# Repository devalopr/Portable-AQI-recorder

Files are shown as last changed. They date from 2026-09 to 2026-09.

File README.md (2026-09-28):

# Portable AQI Recorder — V3 (custom PCB)

A handheld air-quality recorder on a custom main board: an ESP32-C3-MINI-1 module reads a Sensirion SEN5x or SEN6x particulate sensor and an optional SCD4x CO₂ sensor (SCD40, SCD41 or SCD43), shows readings on a 2.4" ST7789 TFT with three buttons, and has Wi-Fi and BLE on the module.

This branch holds the **V3 main PCB only**. Everything else lives elsewhere:

| What | Where |
|---|---|
| ESP32-C3 Super Mini build without a PCB: firmware, Web Bluetooth app, wiring | [V2 branch](https://github.com/devalopr/Portable-AQI-recorder/tree/V2) |
| 18650 battery board (IP5310, USB-C in/out, battery % over PWM) | Separate product: [18650-USB-C-UPS](https://github.com/devalopr/18650-USB-C-UPS) (private) |
| Rev A boards and earlier design history | Git history of this branch (commit `34dd5cf`) |

## Main board (Rev B)

**[hardware/rev-b/main](hardware/rev-b/main/README.md)** — KiCad 10 project, 47 × 76 mm, two layers, fully routed. Start with its README: layout, pin map, connectors, cost, checks and open items before fabrication.

- **Display:** 2.4" 240 × 320 ST7789 TFT on the front, with the three buttons below it. An e-paper display can be fitted instead through an external adapter on J6.
- **Sensors:** SEN5x and SEN6x connectors (fit one PM module) and a CO₂ island for an optional SCD40, SCD41 or SCD43, soldered by hand later. Everything else on the board comes assembled; only the CO₂ sensor and the J6/J8 headers are left unfitted.
- **Power and data:** USB-C J1 is the only input. It takes 5 V and USB data from the battery board's USB-C output, or straight from a charger or computer. Battery % arrives as PWM on J2.
- **Cost:** about $4.63 per board at 1000 (parts, 2-layer fabrication and JLC assembly); see [review/COST.md](hardware/rev-b/main/review/COST.md).

## Repository layout

| Path | Contents |
|---|---|
| [firmware](firmware/README.md) | Main board firmware (PlatformIO). |
| [hardware/rev-b/main](hardware/rev-b/main/README.md) | Schematic, PCB, libraries and 3D models; `review/` has the BOM, placement file, PDF, renders, DRC/ERC reports and routing files. |
| [hardware/rev-b/scripts](hardware/rev-b/scripts) | Python/shell pipeline that generates the schematic and places, routes and checks the board (see "Regenerating" in the main README). |
| [hardware/rev-b/firmware/telemetry](hardware/rev-b/firmware/telemetry/README.md) | ESP32 receiver for the battery board's battery-% PWM signal. |
| [hardware/rev-b/references](hardware/rev-b/references) | Datasheets for parts on this board. |
| [hardware/design-brief.md](hardware/design-brief.md) | The original product brief the boards were designed from. |

## Firmware

**[firmware/](firmware/README.md)** — PlatformIO/Arduino firmware for this board, ported from the V2 firmware: auto-detects SEN5x or SEN6x and any SCD4x, shows AQI and the other readings on the TFT, records to RAM, streams over BLE (compatible with the V2 web app) and shows the battery % from the battery board. It builds but hasn't run on a built board yet.

The board is programmed and logs over its USB-C port (the ESP32-C3's native USB): switch the board on and run `pio run -t upload` in `firmware/`. If it stops appearing, hold OK while switching it on to force the bootloader.

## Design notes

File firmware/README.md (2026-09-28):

# Main board firmware (V3)

PlatformIO / Arduino firmware for the main board Rev B ([hardware/rev-b/main](../hardware/rev-b/main/README.md)). It is a port of the V2 Super Mini firmware to this board's pins, sensors and three buttons. It builds, but **it has not run on a built board yet**; see "Not yet verified" below.

## Build and flash

Needs [PlatformIO](https://platformio.org/) (the VS Code extension or `pip install platformio`). From this folder:

```bash
pio run -t upload
```

```bash
pio device monitor
```

## Programming over USB

Yes: the board is programmed and logs through its USB-C port J1, with no adapter or extra buttons.

- J1's data pair goes to the ESP32-C3's built-in USB Serial/JTAG port (GPIO18/19) through R7/R8 and the D1 ESD protector. A computer sees a USB serial port; esptool (used by `pio run -t upload`) resets the chip into the bootloader and back over USB by itself.
- **The power switch must be on.** SW4 switches the regulators that power the ESP32, so with the switch off the board is invisible to the computer even though USB is plugged in.
- It also works through the battery board: plug the computer into the battery board's input, and the battery board passes USB data to its output, which feeds J1. That pass-through is Full Speed only and untested, so use a direct cable to J1 if it misbehaves.
- **If the port disappears** (e.g. firmware that crashes at boot or reuses GPIO18/19): hold **OK** while switching the power on. GPIO9 low at power-up starts the ROM bootloader, which always comes up on USB. Flash, then switch off and on. TP3 (GPIO9) and TP2 (EN, reset) are also on the back for a test fixture.
- Serial logs use native USB CDC (`ARDUINO_USB_CDC_ON_BOOT`). Don't enable UART0: its TX pin, GPIO21, is the battery-% input.

## What it does

| Feature | Details |
|---|---|
| PM sensor | Auto-detected at boot: SEN50/54/55 on J3 (I²C 0x69) or SEN63C/65/66/68 on J4 (I²C 0x6B). Fit one. |
| CO₂ | Any SCD4x on the CO₂ island (I²C 0x62): SCD40, SCD41 or SCD43, identified at boot and logged. Otherwise the SEN63C/SEN66's built-in CO₂. The SCD4x wins if both are present. |
| AQI | US EPA AQI from PM2.5 and PM10, unchanged from V2 (above 500 continues the 301–500 slope). |
| Display | ST7789 240 × 320 on J5; home screen, full-screen charts. Backlight PWM on GPIO3 (Q1). |
| Battery | Battery % from the battery board's PWM on J2 → GPIO21 (`hardware/rev-b/firmware/telemetry`); shows `--` without it. |
| Recording | RAM ring buffer, 2700 samples (45 min at 1 Hz), charted on the device. |
| BLE | Same service and packet as V2, so the [V2 web app](https://github.com/devalopr/Portable-AQI-recorder/tree/V2/web) works. Two fields are appended (CO₂ ppm u16, battery % u8); the V2 app ignores them and shows SEN6x sensors as "Unknown". |

### Buttons

| Button | Home screen | Chart |
|---|---|---|
| LEFT / RIGHT | Move the selection | Previous / next chart |
| OK | Open the chart for the selection; on the gear, cycle brightness (100/70/40/15 %, remembered) | Back to home |
| Hold OK (0.8 s) | Start / stop recording | Start / stop recording |

Don't hold LEFT or RIGHT while switching on (they are boot-strap pins).

## Configuration

`platformio.ini` holds the display pins and `DISPLAY_ROTATION` (2 = image turned 180° because the display flex exits at the top). If the image comes out upside down on the real panel, change it to 0.

## Not yet verified on hardware

- Display orientation, colour order and inversion (`DISPLAY_ROTATION`, `TFT_RGB_ORDER`, `TFT_INVERSION_OFF`).
- Backlight brightness steps against R28.
- SEN6x start-up timing and each SEN6x variant's detection (only the drivers' interfaces were checked).
- The SCD4x on the island, and its temperature offset with the board running.
- Battery % from a real battery board.
- The e-paper option (J6) has no driver in this firmware; it builds for the TFT only.

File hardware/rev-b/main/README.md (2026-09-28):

# AQI main board — Rev B

Open `AQI_Main.kicad_pro` in KiCad 10. This board mates with the IP5310 battery board, which now lives in its own private repo, [18650-USB-C-UPS](https://github.com/devalopr/18650-USB-C-UPS). It started from the routed Rev A main board, whose design is kept in `review/rev-a-baseline/` as the input to `main_revb_design.py`; the rest of Rev A is in git history.

**47 × 76 mm, two layers, 1.6 mm.** This is 4 mm shorter and 3 mm wider than Rev A, and two layers instead of four. The previous 4-layer, 80 mm version is kept in `review/rev-b-4layer-80mm/` (board, `design.json` and its cost).

Changes in the 2-layer, 47 × 76 mm re-layout:

- **Wider, with mounting lips.** The board grew 1.5 mm on each long side, from 44 to 47 mm, for routing room. Board coordinates keep the Rev A origin, so the board now spans x = −1.5 to 45.5 mm. The outer 1 mm on each side (x = −1.5 to −0.5 and 44.5 to 45.5 mm) is a lip for clamping the board in the case. It carries only the ground pour: no tracks or vias. SW4 moved out 1.5 mm with the edge.

- **Shorter bottom.** Everything below the buttons moved up 4 mm and the bottom edge was cut to match:
  - the ESP32 module, which keeps its antenna at the edge, and its supply caps;
  - USB-C and D1;
  - the J2/J8 headers.

  The limit is USB-C: its shield legs pass through the board and must stay clear of the OK button's pads.
- **CO₂ on top.** The CO₂ island is now at the top of the right column (y = 21–35 mm, under J5), above SEN5x and SEN6x. It is fed through its bottom-right tab instead of the middle tab (see Layout). Set `ISLAND_DY = 0` in `main_revb_2layer.py` to go back to the island at the bottom of the column.
- **Sensor connectors.** J3 (SEN5x, y = 37–49 mm) and J4 (SEN6x, y = 49.8–59.4 mm) sit below the island, 6 mm in from the original right edge. Their mouths face the edge from x = 37.5 mm, leaving 8 mm on the board for the GH plug and for the cable to bend down before it reaches the case.
- **E-paper through an adapter.** The on-board e-paper boost circuit and its 24-pin FPC connector are gone. An unfitted 8-pin header J6 takes their place (see below).
- **Two layers.** The front copper, where only the buttons sit, carries ground plus as few signals as possible. A few critical nets are laid first as fixed routes (see Layout), and the rest are routed around them.

## Front: display and buttons

The front carries only the display and the three buttons. Everything else, including USB-C, is on the back.

- **Display.** A 2.4-inch 240 × 320 ST7789 panel with a 10-way, 1.0 mm-pitch flex.
  - **Size:** 42.72 × 60.26 × 2.5 mm, with a 36.72 × 48.96 mm active area (common datasheet values; you measured about 42.5 × 60 × 2.5 mm).
  - **Position:** centred in the Rev A display envelope, which spans x = 0.64–43.36 mm, y = 1.5–62.46 mm (board origin top-left, seen from the front). The panel itself spans y = 1.85–62.11 mm.
  - **Height:** it sits on 0.2 mm tape, so its front face is 2.7 mm above the board.
  - **Flex:** exits at the top, wraps over the top edge (about 1.5 mm past it) and runs into J5 on the back. The active area therefore sits toward the buttons, and firmware rotates the image.
  - **In the files:** the board-only footprint DS1 carries the panel's 3D model and outline. It isn't in the BOM or the placement file. The envelope is also drawn on Dwgs.User, labelled "TFT DISPLAY BODY (FRONT)".
  - The active-area offsets (3.0 mm at the sides, 3.2 mm at the far end, 8.1 mm at the flex end) and the flex path are typical values, not from your panel's drawing. Check them against the part you buy.
  - Nothing is placed on the front under the panel.
- **Buttons.** SW1 LEFT, SW2 OK and SW3 RIGHT sit in one row directly below the display:
  - centres at x = 9, 22 and 35 mm, y = 66.25 mm;
  - an even 13 mm pitch, centred on the board and the display (x = 22);
  - XKB TS-1187A: 5.1 × 5.1 mm body, 1.5 mm tall;
  - bodies at y = 63.7–68.8 mm, about 1.2 mm below the display edge.

  The switch tops (1.5 mm) are 1.2 mm below the display face (2.7 mm), so the enclosure needs button caps or plungers that reach the front face. The silkscreen labels L / OK / R are under each button.
- **3D models.** They are all in `lib/3d/` and the footprints point at them through `${KIPRJMOD}`; see `lib/3d/README.md`.
  - USB-C uses the LCSC catalogue model shared with the battery board.
  - KiCad 10 has no models for the TS-1187A buttons or the MSK12C02 power switch. They use simplified envelopes built from the footprint and datasheet dimensions, with their build123d sources alongside.

## Cost

About **$4.63 (₹444) per board at 1000** boards:

| At 1000 boards | Per board |
|---|---:|
| Parts | $4.01 |
| 2-layer fabrication, 47 × 76 mm | $0.13 (4-layer, 80 mm was $0.30) |
| JLC assembly | $0.49 |

Five prototypes cost about $31 each, mostly JLC's per-order assembly setup; the bare 2-layer boards are about $2 for five. Details, assumptions and exclusions are in [review/COST.md](review/COST.md). Only the SCD41 (U8) and the J6/J8 headers are unfitted; the CO₂ supply (LDO U7 with C15, C16 and C42, about $0.24) is assembled so the sensor can be soldered in later on its own. The same design with its original parts was about $10.7 (₹1030) at 1000.

## E-paper option (J6, unfitted)

The stationary version can use an e-paper display instead of the TFT. The panel from the Rev A brief, Good Display GDEY037T03, is a bare panel: it needs a boost circuit (about ±15 V gate and source rails) on whatever board its 24-pin flex plugs into. Rev A put that circuit on this board as an unfitted option: 22 parts plus the FPC connector. Rev B leaves the boost circuit to an external adapter instead:

- **Adapter.** Good Display's DESPI-C02 takes the panel's 24-pin flex and makes the rails. The same adapter fits most of Good Display's 24-pin SPI panels, so the main board isn't tied to one panel. A module with its own driver board (for example Waveshare's) also works.
- **J6.** A 1 × 8, 2.54 mm SMD pin header on the back at the top-left edge (pads staggered at x = 3.35 and 6.66 mm, y = 1.5–19.3 mm). Like J8, it is unfitted (DNP) by default and is left out of the JLC BOM and placement files; solder it by hand for an e-paper build. It sits near the board edge, clear of J5, so there's room for the iron. It's surface-mount so no through-hole pads sit under the TFT in the default build. Pin 1 is at the top; the pin names are on the back silkscreen, on the side toward J5.

| J6 pin | DESPI-C02 pin | Signal | ESP32 |
|---:|---|---|---|
| 1 | BUSY | EPD_BUSY | GPIO20 |
| 2 | RES | DISP_RST | GPIO7 |
| 3 | D/C | DISP_DC | GPIO10 |
| 4 | CS | DISP_CS | GPIO4 |
| 5 | SCK | DISP_SCK | GPIO5 |
| 6 | SDI | DISP_MOSI | GPIO6 |
| 7 | GND | GND | |
| 8 | 3.3V | +3V2 (3.19 V) | |

A straight 8-way female-to-female cable maps J6 pin n to DESPI-C02 pin n. Waveshare modules use the same signals in reverse order (VCC, GND, DIN, CLK, CS, DC, RST, BUSY).

The display SPI, CS, DC and reset are shared with the TFT, so **fit one display only**. The adapter's supply comes from the +3V2 rail; e-paper refresh current is small. Firmware still has to supply a driver for the chosen panel: ESPHome has no working UC8253 (GDEY037T03) driver yet (see the Rev A brief), so either pick a panel ESPHome supports or bench-test a custom component.

## Interface to the battery board

- **USB-C J1 is the only power and data input.** It is the same SHOU HAN TYPE-C 16P L6.5 (LCSC C49287211) as the battery board's J1 and J7, using that board's footprint (checked against the maker's drawing) and 3D model. It is on the back, at x = 26.7 mm on the bottom edge (y = 76), with its mouth flush with the edge. That is about 11 mm nearer the centre than in Rev A. Plug it into the battery board's USB-C output J7, which carries 5 V plus USB data passed through from the battery board's input port. It can also plug straight into a computer or adapter.
- **J2: straight 2.54 mm Dupont header for battery %** (hanxia HX PZ2.54-1x2P ZZ, LCSC C32713268), back side, bottom-right, pin 1 at (33.85, 72.1) mm. The pins stand up from the back, toward the battery board; nothing overhangs the edge. Pin 1 = GND, pin 2 = BAT_PWM, the same order as battery J9, so a straight female-female jumper works. R33 (10 kΩ) pulls BAT_PWM up to +3V2; R34 (1 kΩ) feeds GPIO21. Encoding and receiver: `../firmware/telemetry/README.md`.
- **J8: straight Dupont header for external 5 V, unpopulated** (same part), next to J2 (pin 1 at x = 39.95 mm). Pin 1 = GND, pin 2 = 5 V in. D2 (B5819W Schottky, fitted) feeds +5V_SYS, the same point as USB VBUS. The switch and regulators work as normal, and the diode stops the board back-feeding the external supply. A supply above USB VBUS + 0.3 V can back-feed a connected USB host, so don't plug USB into a computer while an external 5 V is attached.
- Removed with the 10-way JST GH link:
  - the TS3USB30E USB data mux;
  - the TPS2116 power mux;
  - their FETs and resistors;
  - C4, C5, C6 and R24.

  No I2C runs to the battery board any more.

## Cost-down changes (same functions)

| Part | Rev A | Rev B |
|---|---|---|
| U5, U6 bucks | TPS62160 (MSOP-8) | Silergy SY8089A1AAC (SOT-23-5). The datasheet's optional feed-forward caps are omitted. |
| Buttons | MCP23008 I2C expander + C&K KMR2 | Straight to GPIOs; XKB TS-1187A 5.1 mm switches. U9, C17, R23 and R25 removed. |
| Backlight | STCS05A current sink (not stocked at JLC) | AO3400A low-side switch Q1 with R28 = 33 Ω 1206 (~55 mA at Vf 3.1 V). Still PWM-dimmable on GPIO3; the current is set by the resistor, not regulated. |
| Power switch | C&K JS102011SAQN | Shou Han MSK12C02; its actuator sticks out about 1.1 mm past the right edge. |
| USB-C | GCT USB4105 | SHOU HAN TYPE-C 16P L6.5, the battery board's part ($0.047 at 1000, against $0.103 for the HRO TYPE-C-31-M-12 it replaced) |
| Sensor connectors J3, J4 | JST GH | XYECO GH-compatible clones, same footprint |
| ESD, MCU | ST USBLC6-2SC6, ESP32-C3-MINI-1-H4 | Tech Public USBLC6-2SC6, ESP32-C3-MINI-1-H4X (same footprint) |

Every fitted part has an LCSC code in the schematic. `review/jlc-bom.csv` and `review/jlc-cpl.csv` are ready for JLCPCB assembly. The board is double-sided: the three buttons are on the front and everything else is on the back.

The TFT connector (TE 1-84953-0, $0.44) stays: no cheap top-contact 1.0 mm 10-pin FPC connector is stocked, and the display needs top contact.

## Firmware pin map

The firmware in [firmware/](../../../firmware/README.md) uses this map. The board is programmed and logs over J1 (native USB); see that README.

| ESP32 GPIO | Function |
|---|---|
| 10 | Display DC |
| 4 | Display CS |
| 5 | Display SCK |
| 6 | Display MOSI |
| 7 | Display RST |
| 8 | LEFT button, active low, R3 pull-up |
| 9 | OK button, active low, R2 pull-up. Hold OK while resetting to enter the ROM bootloader. |
| 2 | RIGHT button, active low, R4 pull-up |
| 21 | BAT_PWM input through R34. Use native USB for logs; do not enable UART TX on GPIO21. |
| 3 | Backlight PWM, now driving a MOSFET gate (R27 pull-down) |
| 0 | I²C SDA (SEN5x at 0x69, SEN6x at 0x6B, SCD4x at 0x62) |
| 1 | I²C SCL |
| 20 | E-paper BUSY (J6 pin 1), input; also the ROM UART RX |
| 18, 19 | Native USB D−, D+ (to J1 through R7/R8 and D1) |

GPIO2, 8 and 9 are boot-strap pins. Don't hold LEFT or RIGHT while resetting; OK held at reset is the intended download mode. The buttons need a pull-up at reset, which R2–R4 provide; there's no I2C expander any more.

The 2-layer layout changed the display pins so they leave the module in the TFT connector's order (DC, CS, SCK, MOSI, RST); this lets the bus run without crossings:

| | Rev A and 4-layer Rev B | 2-layer Rev B |
|---|---|---|
| DC | GPIO5 | GPIO10 |
| CS | GPIO10 | GPIO4 |
| SCK | GPIO4 | GPIO5 |

MOSI (GPIO6) and RST (GPIO7) are unchanged. The display SPI goes through the GPIO matrix either way. The table above is the complete pin map.

## Layout

Two layers. Nearly every part is on the back, so the back carries most signals, and the front carries ground plus the fixed routes below.

- **Ground.**
  - Both layers are poured with GND and stitched with 228 vias:
    - one beside every ground pad, placed before routing so the router must leave room for it;
    - a 2 mm edge fence;
    - a 3 mm field grid;
    - repair vias for any pocket.
  - All ground copper is one connected area except the CO₂ island, which joins through the bridge (see below).
  - The front pour covers about 76% of the board and the back about 64%.
- **Ground neck.** The CO₂ island's slots cut the right half of the board between y = 21 and 35 mm, so every return current between the top and bottom halves passes through the neck on the left. The front copper at x = 8.5–16 mm, y = 23.3–35.5 mm is kept free of signal tracks; vias are allowed. That keeps a continuous 7.5 mm ground bridge there.
- **Fixed routes** (drawn before autorouting, in `main_revb_2layer.py`):
  - **Display SPI.** DC, CS, SCK, MOSI and RST run as a 5-lane front bus. It starts with vias above the module's top pins, runs up the left edge and along y = 21–23 mm, then drops through vias beside J5's pads.
  - **Backlight PWM.** It takes the outermost left-edge lane.
  - **CO₂ island.** The island's copper enters through its 2.5 mm bottom-right tab (x = 41.5–44 mm, y = 34–35 mm); the left tab is mechanical only, with no copper. U8 (SCD41) is turned so its SDA, SCL, VDD and GND pins face the tab. SDA and GND cross on the back, SCL and +3V3_CO2 on the front, and they run down to U7 (the CO₂ LDO, beside J3) and the I²C bus. The widened strip beside the island (x = 44–45.5 mm) has no copper at all, so the island stays thermally isolated. Tracks keep 0.35 mm from all slot edges. The U8 footprint takes any SCD4x: the BOM lists the SCD41, but an SCD40 (cheaper, specified to 2000 ppm) or SCD43 (better accuracy) fits and works with the firmware unchanged.
  - **Buttons.**
    - GPIO8 (LEFT) runs straight down the front.
    - GPIO9 (OK) goes past the module corner on the back, then down the front.
    - GPIO2 (RIGHT) leaves pin 5 on the back, up a via in the lane beside the module's centre ground pads, then along the front between the button pad rows.
  - **Battery PWM (GPIO21).** It crosses the bottom band on the front at y = 65.45 mm.
  - **E-paper BUSY.** It runs up the front from the module to TP5; the router takes it on to J6.
  - **USB.** The module-side pair threads past the pin-30/31 vias. D1's ground goes through a via under its body to the USB-C shield.
  - **Load switch U4.** CT, ON and QOD go directly to C8, R15 and R16.
- **Placement changes for two layers.**
  - U4 (load switch) took the CO₂ LDO U7's place and is turned 180°, so its control pins face their parts. U7 moved beside J3's 5 V pin, just below the island.
  - R7/R8 swapped, so the USB pair keeps the same order from the module through the resistors to D1.
  - R27, the backlight gate pull-down, sits beside Q1 between its gate and source pins (it was at the end of the left-edge backlight lane, where J6 now is).
  - C16 (the SCD41's 10 µF supply cap, assembled) is off the island, below U7's output (x = 25 mm, y = 42 mm), about 7 mm from the sensor body and across the slot. Hot air used to fit the SCD41 later won't lift it. It also acts as U7's bulk output cap. The island itself now carries only the sensor.
  - TP2/TP3 moved to the left edge (the touch-up moves TP3 beside R3 only if the router can't reach it there); C7, R2 and R3 moved up 1.5–3 mm to open a fan-out band above the module's top pins.
- **Routing and power.**
  - Freerouting routes the rest, with the back preferred. An A* finisher (`astar_finish.py`) closes what the router leaves, moving other tracks only when everything it moves reconnects.
  - Power nets are 0.6 mm except a few short 0.4–0.5 mm squeezes (about 6.5 mm of +3V2, 5 mm of +5V_SYS and 3 mm of +5V_SW). +3V3_CO2 is 0.25 mm through the island tab; the SCD41's peak draw is under 0.2 A.
- **Bucks.** Each SY8089's input cap, IC and inductor sit together on the back. Their grounds join the back pour, with vias to the front plane beside each ground pad.

## Checks (review/)

- **Results:** ERC 0. DRC with schematic parity: 0 errors, 0 warnings, 0 unconnected, 0 parity issues.
- **Exports:** `AQI_Main.pdf`, `netlist.xml`, `engineering-bom.csv`, `jlc-bom.csv`, `jlc-cpl.csv`, `COST.md`, `price-snapshot-2026-09-27.json`, `drc.json`, `erc.json`, layer SVGs and renders.
- **3D renders:** `main-top.png`, `main-bottom.png` and the two angled views. They include the display panel and its flex.
- `rev-a-baseline/` holds the untouched Rev A board and its `design.json` (the input to `main_revb_design.py`); `rev-b-4layer-80mm/` holds the 4-layer, 80 mm Rev B that the 2-layer layout starts from.
- `routing/` holds the Freerouting input and output (`AQI_Main.dsn`, `.ses`, logs) and the list of fixed routes.

## Regenerating

Needs KiCad 10, a Java 25+ runtime (Homebrew `openjdk`) and Freerouting 2.4.1 (`~/Applications/freerouting/freerouting-2.4.1.jar`, or set `FREEROUTING`). Run from `../scripts`:

1. `main_revb_design.py` rebuilds `design.json` and the schematic.
2. Export `review/netlist.xml` (kicad-cli `sch export netlist --format kicadxml`).
3. `main_revb_2layer.sh` starts from `review/rev-b-4layer-80mm/` and runs each stage in turn:
   1. **Placement:** strips the copper, cuts the outline, moves parts, lays the fixed routes and ground fan-out, and writes the DSN.
   2. **Routing:** Freerouting, then the A* finisher.
   3. **Ground:** stitching and island repair.
   4. **Touch-up:** `main_revb_2layer_touchup.py`.
   5. **Sync:** writes positions back to `design.json`.
   6. **DRC.**
4. `main_revb_cost.py` recomputes `review/COST.md`. It picks up the layer count and board size from the board.

Freerouting's result depends on its input, so a rerun after any change gives a different board, and the finisher may need a hand. The 4-layer flow (`main_revb_layout.py`) still rebuilds the 80 mm board.

Hand edits made in KiCad are not captured by the scripts. Once you edit the `.kicad_pcb` by hand, treat it as the source of truth.

## Open items before fabrication

1. **Antenna.** The module sits on the back, facing the battery board. Keep the 18650 cell, holder terminals and cables away from the bottom-left corner.
   - With the shorter board, the antenna keepout ends about 1.3 mm from the LEFT button's pads (it was 5 mm).
   - USB-C is about 6 mm from the keepout.
   - Measure Wi-Fi/BLE range in the enclosure, with the USB cable plugged in.
   - On two layers the module also has no inner ground plane under it; its ground pads stitch to the front pour instead.
2. **Backlight current.** R28 = 33 Ω assumes a ~3.1 V LED forward voltage at ~55 mA. Check brightness and current on the actual panel and adjust R28.
3. **Enclosure.** Allow for:
   - the 47 × 76 mm board, with the 1 mm copper-free clamping lips on both long sides;
   - the J2/J8 straight headers: about 8.5 mm tall on the back, plus the Dupont housings (your CAD test fit shows room);
   - J3/J4 mouths at x = 37.5 mm, with the GH plug and cable bend in the 8 mm to the right edge;
   - the SW4 actuator about 1.1 mm past the right edge;
   - USB-C on the back at x = 26.7 mm;
   - the button row at x = 9, 22, 35 mm, y = 66.25 mm, with caps or plungers to reach past the display thickness.
4. **2-layer review.** Before ordering, look over the routing in KiCad, especially:
   - the CO₂ island's tab feed;
   - the U4 corner by the slot;
   - the left-edge display bus.
5. **Firmware.** [../../../firmware](../../../firmware/README.md) implements the pin map above (buttons on GPIO8/9/2, battery % from BAT_PWM, the display on DC = GPIO10, CS = GPIO4, SCK = GPIO5). On the first board, check the display orientation and colours, backlight steps and sensor detection. The e-paper build still needs BUSY on GPIO20 and a driver for the chosen panel.
6. **USB-C supply and fit.** LCSC had only 2,553 of C49287211 in stock (2026-09-27). The battery board uses two per set, so 1000 sets need 3000. Reserve stock or approve the HRO TYPE-C-31-M-12 as the alternate, which needs a footprint and breakout change. SHOU HAN's drawing is for 0.8 mm boards, so check shell-leg soldering and retention on this 1.6 mm board. The battery board has the same open check. In JLC's placement preview, confirm J1's rotation: its footprint comes from the EasyEDA catalogue.
7. **Pricing.** Get a real JLCPCB quote. The cost uses catalogue tiers and published assembly rates, not a quotation.
8. **Carried over from Rev A:**
   - Finish the enclosure CAD: TFT flex bend radius, connector latch access, button caps and travel, PCB retention on the lips, sensor airflow. Support the CO₂ island without a conductive metal bridge.
   - Standalone sensing needs a suitable 5 V supply (start with a 1 A or larger adapter); the board does not detect Type-C advertised current.
   - Check MLCC effective capacitance under DC bias for the fitted parts.
   - Validate the CO₂ temperature offset with Wi-Fi, the display and the PM sensor running; couple the CO₂ opening to ambient air and shield it from PM fan turbulence.
   - Validate USB signal quality, regulator transients and backlight PWM on the built board.

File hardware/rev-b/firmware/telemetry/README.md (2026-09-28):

# Battery PWM interface, revision 1

Current battery schematic: `integrated-power/AQI_IP5310_Power.kicad_sch` in the [18650-USB-C-UPS](https://github.com/devalopr/18650-USB-C-UPS) repo, which also holds the CH32 transmitter firmware and a copy of this folder. The older `cost-revision` is preserved for history. Portable ADC/estimator and charging integration now lives in that repo's `firmware/control`; target hardware binding remains unfinished.
Main schematic: `../../main-pwm/AQI_Main.kicad_sch`.
These are circuit revisions; the existing routed boards do not implement this interface yet. Do not manufacture from old STEP/ZIP/Gerber files as if they did.

## Electrical connection

Current integrated-power revision: J9 pin 2 and TP8 carry open-drain BAT_PWM; J9 pin 1 is GND. The receiver supplies its 10k pull-up to 3.3V. J3/GH and its USB branch have been removed. Older main-pwm hardware still brings this signal to GH pin 7 and needs an adapter or connector revision. Older I2C battery-interface firmware is incompatible.

Q5 is a 2N7002 open-drain output, source to GND, gate driven by CH32V003 PC1/package pin11. R49 (100k) holds the gate off during reset. Connect a **10k pullup to the host's 3.3V or 5V logic supply**, and share ground. Do not pull up to battery voltage. No pullup is fitted on the battery board, avoiding back-power into an unpowered host. Intended for short internal/hobby wiring, not a long external cable or an ESD-qualified industrial port.

Main revision: R33 pulls BAT_PWM up to +3V2; R34 (1k) connects it to ESP32 GPIO21/package pin31. TP4 is now BAT_PWM_MCU. The resistor limits contention during ROM UART output at startup. Use native USB logging and configure GPIO21 as input; do not enable UART TX on it. Sensor I2C, native USB and e-paper BUSY/GPIO20 are unchanged. Main schematic ERC and all intended connected pins in the exported netlist have been checked.

## Encoding

100Hz nominal, 10ms frame. **HIGH duty** = 10% + 0.8 × percentage, so 0% battery is 1ms high, 50% is 5ms high, and 100% is 9ms high. The MOSFET inverts its gate signal; the CH32 driver accounts for that.

Decode `percent = (high_time / period - 0.1) / 0.8 * 100`. No transitions means unavailable, never 0% or 100%. Receiver accepts periods 9–11ms, tolerates 9–91% wire duty at the endpoints, requires three valid complete frames, and expires the last value after 100ms. This is an approximate voltage-based estimate, not a calibrated fuel gauge.

## Firmware

- `battery_pwm.h`: shared encoding/decoding, no framework dependency.
- The CH32V003 transmitter (`battery_pwm_ch32.c`) is battery-board firmware and lives in the [18650-USB-C-UPS](https://github.com/devalopr/18650-USB-C-UPS) repo (`firmware/telemetry`), which has the full copy of this interface.
- `BatteryPwmReader.h/.cpp`: ESP32 Arduino receiver using a GPIO edge interrupt, no busy-wait pulse reads.
- `receiver_example.cpp` and `platformio.ini`: standalone GPIO21/USB diagnostic example, successfully built for ESP32-C3 using Arduino-ESP32 2.0.14. This example is not the AQI application and should not replace it wholesale.

Build receiver: `pio run -d hardware/rev-b/firmware/telemetry` from repository root.
Run protocol test: `clang -Wall -Wextra -Werror hardware/rev-b/firmware/telemetry/test_protocol.c -o /tmp/aqi-pwm-test && /tmp/aqi-pwm-test`.

Hardware validation still required: waveform/polarity and startup on both boards, 3.3V/5V pullups, host unpowered behavior, estimator calibration, and worst-case ISR latency. No hardware test is claimed.

Sources: WCH official SDK https://github.com/openwch/ch32v003 ; ESP32-C3-MINI pinout https://documentation.espressif.com/esp32-c3-mini-1_datasheet_en.html .

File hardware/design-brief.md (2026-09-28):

# AQI recorder design brief

> **Status (V3):** this is the original product brief, written for Rev A. The current main board is [rev-b/main](rev-b/main/README.md), which supersedes the Rev A sizes and decisions below. The battery board sections now belong to the separate [18650-USB-C-UPS](https://github.com/devalopr/18650-USB-C-UPS) repo. Rev A files and the early research it mentions are in git history (commit `34dd5cf`).

The implementation and current decisions are documented in the Rev A README (git history; the current board is described in [rev-b/main](rev-b/main/README.md)). Main PCB size is 44 × 80 mm, following the user's request to stay close to 80 mm. The TFT uses a rear top-contact connector; its flex contacts face away from the board. The battery board uses a standard 65 mm cell with PCB protection and a 10-way JST GH internal link.

The final KiCad files are engineering review prototypes. See the validation report and release items in the README before fabrication. Earlier circuit proposals under references/early-research are superseded.

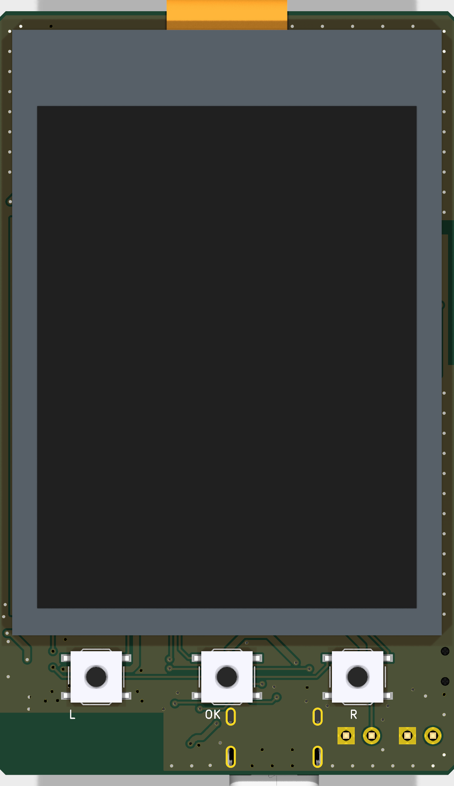
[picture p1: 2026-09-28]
hardware/rev-b/main/review/main-top.png

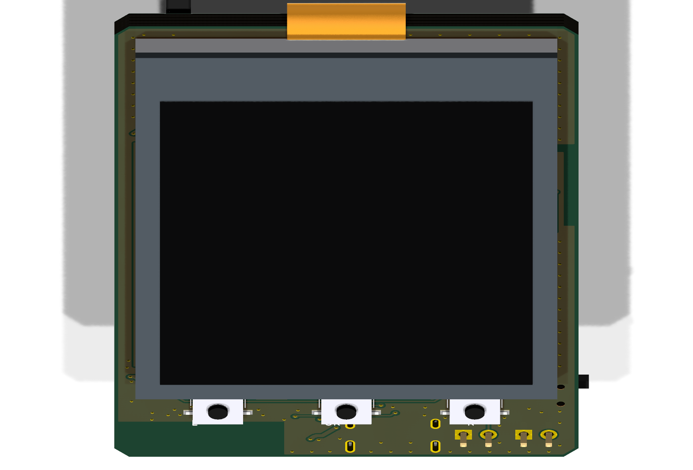
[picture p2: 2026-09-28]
hardware/rev-b/main/review/main-top-angled.png

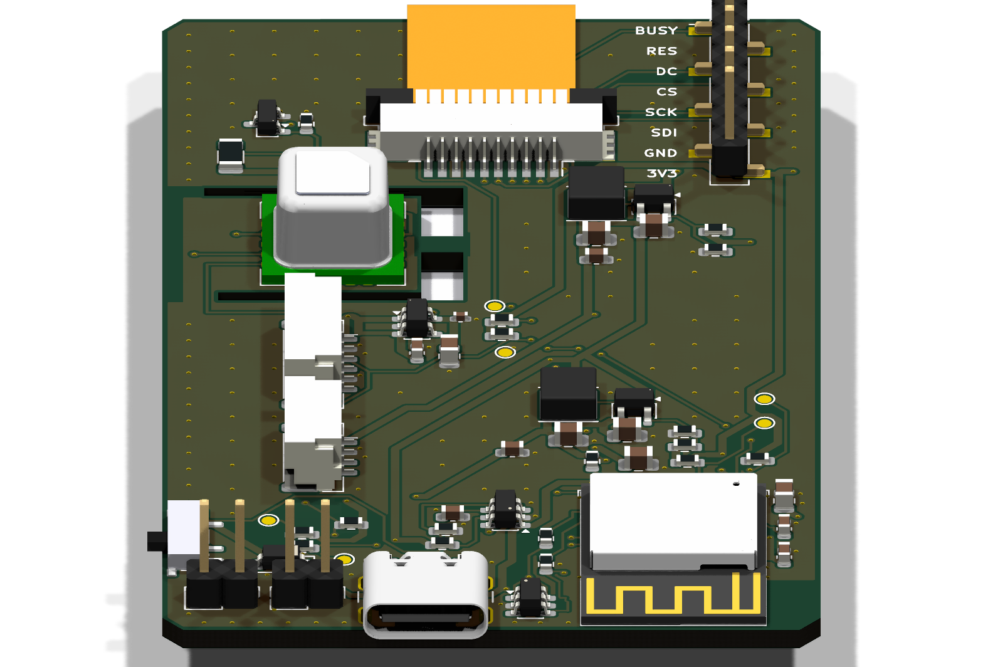
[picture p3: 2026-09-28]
hardware/rev-b/main/review/main-bottom-angled.png

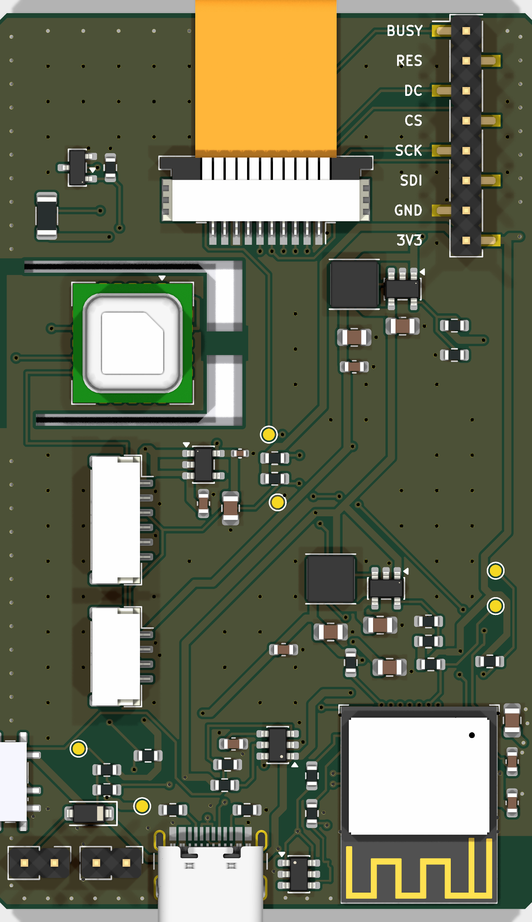
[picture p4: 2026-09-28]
hardware/rev-b/main/review/main-bottom.png

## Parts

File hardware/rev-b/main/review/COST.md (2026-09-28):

# Main board Rev B — cost estimate

Catalogue snapshot 2026-09-27 (PCBParts JLC/LCSC, `price-snapshot-2026-09-27.json`), USD, INR at 96/USD. Default TFT + SEN5x/SEN6x build; DNP parts (the SCD41 U8 and the J6/J8 headers) excluded; the CO2 supply (U7, C15, C16, C42) is fitted. JLCPCB Standard PCBA, double-sided (buttons on the front, everything else including USB-C on the back). Not a quotation.

Solder joints per board: 222 SMT, 6 through-hole. 33 unique placed parts.

| Per board | 5 prototypes | 1000 boards |
|---|---:|---:|
| Parts | $5.95 (INR 572) | $4.01 (INR 385) |
| PCB fabrication (2-layer, 47 x 76 mm) | $0.40 (INR 38) | $0.13 (INR 12) |
| Assembly (setup, stencil, feeders, joints) | $24.78 (INR 2378) | $0.49 (INR 47) |
| **Total** | $31.13 (INR 2988) | $4.63 (INR 444) |

Excludes shipping, import duty and GST, programming/test, the display, PM/CO2 sensors, enclosure and the battery board. JLC may add attrition parts; small orders also pay per-order minimums.

## Parts at 1000 boards

| Refs | Part | LCSC | Library | Qty | Unit $ | Line $ |
|---|---|---|---|---:|---:|---:|
| U1 | ESP32-C3-MINI-1-H4X | C41349510 | extended | 1 | 2.1209 | 2.121 |
| J5 | TFT TOP CONTACT | C3168738 | extended | 1 | 0.4418 | 0.442 |
| C10,C13 | 22uF 10V | C45783 | basic | 2 | 0.1116 | 0.223 |
| C2,C7,C9,C12,C16 | 10uF 25V | C15850 | basic | 5 | 0.0442 | 0.221 |
| U4 | TPS22917DBVR | C2681320 | extended | 1 | 0.1967 | 0.197 |
| U7 | TPS7A2033PDBVR | C2862740 | extended | 1 | 0.1207 | 0.121 |
| C1,C15 | 1uF 16V | C15849 | basic | 2 | 0.0543 | 0.109 |
| U5,U6 | SY8089A1AAC | C479074 | extended | 2 | 0.0520 | 0.104 |
| L1,L2 | 2.2uH SWPA4020S | C83423 | extended | 2 | 0.0442 | 0.088 |
| Q1 | AO3400A | C20917 | basic | 1 | 0.0520 | 0.052 |
| J1 | USB-C / standalone | C49287211 | extended | 1 | 0.0470 | 0.047 |
| J3 | SEN5x / 5V | C51940119 | extended | 1 | 0.0434 | 0.043 |
| SW4 | POWER / MSK12C02 | C431540 | extended | 1 | 0.0410 | 0.041 |
| J4 | SEN6x / 3.3V | C51940118 | extended | 1 | 0.0359 | 0.036 |
| D1 | USBLC6-2SC6 | C2827654 | extended | 1 | 0.0309 | 0.031 |
| C3,C11,C14 | 100nF 25V | C14663 | basic | 3 | 0.0073 | 0.022 |
| D2 | B5819W | C8598 | basic | 1 | 0.0192 | 0.019 |
| SW1 | LEFT | C318884 | basic | 1 | 0.0138 | 0.014 |
| SW2 | OK | C318884 | basic | 1 | 0.0138 | 0.014 |
| SW3 | RIGHT | C318884 | basic | 1 | 0.0138 | 0.014 |
| R15,R17,R19,R27 | 100kR | C25803 | basic | 4 | 0.0024 | 0.010 |
| J2 | BAT PWM / Dupont | C32713268 | extended | 1 | 0.0088 | 0.009 |
| C8 | 1nF 25V | C1588 | basic | 1 | 0.0068 | 0.007 |
| R1-R4,R33 | 10kR | C25804 | basic | 5 | 0.0013 | 0.006 |
| R21,R22 | 4.7kR | C23162 | basic | 2 | 0.0022 | 0.004 |
| C42 | 100nF 16V | C1525 | basic | 1 | 0.0034 | 0.003 |
| R20 | 22kR | C31850 | basic | 1 | 0.0031 | 0.003 |
| R28 | 33R | C25375 | extended | 1 | 0.0027 | 0.003 |
| R7,R8 | 22R | C23345 | basic | 2 | 0.0013 | 0.003 |
| R16 | 100R | C22775 | basic | 1 | 0.0025 | 0.003 |
| R5,R6 | 5.1kR | C23186 | basic | 2 | 0.0012 | 0.002 |
| R34 | 1kR | C21190 | basic | 1 | 0.0020 | 0.002 |
| R18 | 23.2kR | C49656146 | extended | 1 | 0.0011 | 0.001 |

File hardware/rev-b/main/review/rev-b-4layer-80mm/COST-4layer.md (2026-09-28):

# Main board Rev B — cost estimate

Catalogue snapshot 2026-09-27 (PCBParts JLC/LCSC, `price-snapshot-2026-09-27.json`), USD, INR at 96/USD. Default TFT + SEN5x/SEN6x build; DNP parts (e-paper, CO2, J8 header) excluded. JLCPCB Standard PCBA, double-sided (buttons on the front, everything else including USB-C on the back). Not a quotation.

Solder joints per board: 211 SMT, 6 through-hole. 31 unique placed parts.

| Per board | 5 prototypes | 1000 boards |
|---|---:|---:|
| Parts | $5.58 (INR 536) | $3.80 (INR 365) |
| PCB fabrication (4-layer, 44 x 80 mm) | $1.60 (INR 154) | $0.30 (INR 28) |
| Assembly (setup, stencil, feeders, joints) | $24.15 (INR 2318) | $0.47 (INR 45) |
| **Total** | $31.33 (INR 3008) | $4.57 (INR 439) |

Excludes shipping, import duty and GST, programming/test, the display, PM/CO2 sensors, enclosure and the battery board. JLC may add attrition parts; small orders also pay per-order minimums.

## Parts at 1000 boards

| Refs | Part | LCSC | Library | Qty | Unit $ | Line $ |
|---|---|---|---|---:|---:|---:|
| U1 | ESP32-C3-MINI-1-H4X | C41349510 | extended | 1 | 2.1209 | 2.121 |
| J5 | TFT TOP CONTACT | C3168738 | extended | 1 | 0.4418 | 0.442 |
| C10,C13 | 22uF 10V | C45783 | basic | 2 | 0.1116 | 0.223 |
| U4 | TPS22917DBVR | C2681320 | extended | 1 | 0.1967 | 0.197 |
| C2,C7,C9,C12 | 10uF 25V | C15850 | basic | 4 | 0.0442 | 0.177 |
| U5,U6 | SY8089A1AAC | C479074 | extended | 2 | 0.0520 | 0.104 |
| L1,L2 | 2.2uH SWPA4020S | C83423 | extended | 2 | 0.0442 | 0.088 |
| C1 | 1uF 16V | C15849 | basic | 1 | 0.0614 | 0.061 |
| Q1 | AO3400A | C20917 | basic | 1 | 0.0520 | 0.052 |
| J1 | USB-C / standalone | C49287211 | extended | 1 | 0.0470 | 0.047 |
| J3 | SEN5x / 5V | C51940119 | extended | 1 | 0.0434 | 0.043 |
| SW4 | POWER / MSK12C02 | C431540 | extended | 1 | 0.0410 | 0.041 |
| J4 | SEN6x / 3.3V | C51940118 | extended | 1 | 0.0359 | 0.036 |
| D1 | USBLC6-2SC6 | C2827654 | extended | 1 | 0.0309 | 0.031 |
| C3,C11,C14 | 100nF 25V | C14663 | basic | 3 | 0.0073 | 0.022 |
| D2 | B5819W | C8598 | basic | 1 | 0.0192 | 0.019 |
| J2 | BAT PWM / Dupont | C32713261 | extended | 1 | 0.0143 | 0.014 |
| SW1 | LEFT | C318884 | basic | 1 | 0.0138 | 0.014 |
| SW2 | OK | C318884 | basic | 1 | 0.0138 | 0.014 |
| SW3 | RIGHT | C318884 | basic | 1 | 0.0138 | 0.014 |
| R15,R17,R19,R27 | 100kR | C25803 | basic | 4 | 0.0024 | 0.010 |
| C8 | 1nF 25V | C1588 | basic | 1 | 0.0068 | 0.007 |
| R1-R4,R33 | 10kR | C25804 | basic | 5 | 0.0013 | 0.006 |
| R21,R22 | 4.7kR | C23162 | basic | 2 | 0.0022 | 0.004 |
| R20 | 22kR | C31850 | basic | 1 | 0.0031 | 0.003 |
| R28 | 33R | C25375 | extended | 1 | 0.0027 | 0.003 |
| R7,R8 | 22R | C23345 | basic | 2 | 0.0013 | 0.003 |
| R16 | 100R | C22775 | basic | 1 | 0.0025 | 0.003 |
| R5,R6 | 5.1kR | C23186 | basic | 2 | 0.0012 | 0.002 |
| R34 | 1kR | C21190 | basic | 1 | 0.0020 | 0.002 |
| R18 | 23.2kR | C49656146 | extended | 1 | 0.0011 | 0.001 |

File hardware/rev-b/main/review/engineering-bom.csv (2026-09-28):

Refs | Value | Footprint | MPN | Manufacturer | LCSC | DNP | Qty
C1,C15 | 1uF 16V | Capacitor_SMD:C_0603_1608Metric |  |  | C15849 |  | 2
C2,C7,C9,C12,C16 | 10uF 25V | Capacitor_SMD:C_0805_2012Metric |  |  | C15850 |  | 5
C3,C11,C14 | 100nF 25V | Capacitor_SMD:C_0603_1608Metric |  |  | C14663 |  | 3
C8 | 1nF 25V | Capacitor_SMD:C_0603_1608Metric |  |  | C1588 |  | 1
C10,C13 | 22uF 10V | Capacitor_SMD:C_0805_2012Metric |  |  | C45783 |  | 2
C42 | 100nF 16V | Capacitor_SMD:C_0402_1005Metric |  |  | C1525 |  | 1
D1 | USBLC6-2SC6 | Package_TO_SOT_SMD:SOT-23-6 | USBLC6-2SC6 | TECH PUBLIC | C2827654 |  | 1
D2 | B5819W | Diode_SMD:D_SOD-123 | B5819W SL | Changjiang | C8598 |  | 1
J1 | USB-C / standalone | AQI:USB-C-SMD_TYPE-C-16P-L6.5 | TYPE-C 16P L6.5 | SHOU HAN | C49287211 |  | 1
J2 | BAT PWM / Dupont | Connector_PinHeader_2.54mm:PinHeader_1x02_P2.54mm_Vertical | HX PZ2.54-1x2P ZZ | hanxia | C32713268 |  | 1
J3 | SEN5x / 5V | Connector_JST:JST_GH_SM06B-GHS-TB_1x06-1MP_P1.25mm_Horizontal | XY-SM06B-GHS-TB | XYECO | C51940119 |  | 1
J4 | SEN6x / 3.3V | Connector_JST:JST_GH_SM04B-GHS-TB_1x04-1MP_P1.25mm_Horizontal | XY-SM04B-GHS-TB | XYECO | C51940118 |  | 1
J5 | TFT TOP CONTACT | Connector_FFC-FPC:TE_1-84953-0_1x10-1MP_P1.0mm_Horizontal | 1-84953-0 | TE Connectivity | C3168738 |  | 1
J6 | E-PAPER ADAPTER (DNP) | Connector_PinHeader_2.54mm:PinHeader_1x08_P2.54mm_Vertical_SMD_Pin1Left | 2.54mm 1x08 SMD pin header |  |  | DNP | 1
J8 | 5V EXT / Dupont (DNP) | Connector_PinHeader_2.54mm:PinHeader_1x02_P2.54mm_Vertical | HX PZ2.54-1x2P ZZ | hanxia | C32713268 | DNP | 1
L1,L2 | 2.2uH SWPA4020S | Inductor_SMD:L_Sunlord_SWPA4020S | SWPA4020S2R2MT | Sunlord | C83423 |  | 2
Q1 | AO3400A | Package_TO_SOT_SMD:SOT-23 | AO3400A | Alpha & Omega | C20917 |  | 1
R1-R4,R33 | 10kR | Resistor_SMD:R_0603_1608Metric |  |  | C25804 |  | 5
R5,R6 | 5.1kR | Resistor_SMD:R_0603_1608Metric |  |  | C23186 |  | 2
R7,R8 | 22R | Resistor_SMD:R_0603_1608Metric |  |  | C23345 |  | 2
R15,R17,R19,R27 | 100kR | Resistor_SMD:R_0603_1608Metric |  |  | C25803 |  | 4
R16 | 100R | Resistor_SMD:R_0603_1608Metric |  |  | C22775 |  | 1
R18 | 23.2kR | Resistor_SMD:R_0603_1608Metric |  |  | C49656146 |  | 1
R20 | 22kR | Resistor_SMD:R_0603_1608Metric |  |  | C31850 |  | 1
R21,R22 | 4.7kR | Resistor_SMD:R_0603_1608Metric |  |  | C23162 |  | 2
R28 | 33R | Resistor_SMD:R_1206_3216Metric |  |  | C25375 |  | 1
R34 | 1kR | Resistor_SMD:R_0603_1608Metric |  |  | C21190 |  | 1
SW1 | LEFT | Button_Switch_SMD:SW_Push_1P1T_XKB_TS-1187A | TS-1187A-B-A-B | XKB | C318884 |  | 1
SW2 | OK | Button_Switch_SMD:SW_Push_1P1T_XKB_TS-1187A | TS-1187A-B-A-B | XKB | C318884 |  | 1
SW3 | RIGHT | Button_Switch_SMD:SW_Push_1P1T_XKB_TS-1187A | TS-1187A-B-A-B | XKB | C318884 |  | 1
SW4 | POWER / MSK12C02 | Button_Switch_SMD:SW_SPDT_Shouhan_MSK12C02 | MSK12C02 | SHOU HAN | C431540 |  | 1
TP1 | GND | TestPoint:TestPoint_Pad_D1.0mm |  |  |  |  | 1
TP2 | MCU_EN | TestPoint:TestPoint_Pad_D1.0mm |  |  |  |  | 1
TP3 | BOOT_GPIO9 | TestPoint:TestPoint_Pad_D1.0mm |  |  |  |  | 1
TP4 | BAT_PWM_MCU | TestPoint:TestPoint_Pad_D1.0mm |  |  |  |  | 1
TP5 | EPD_BUSY | TestPoint:TestPoint_Pad_D1.0mm |  |  |  |  | 1
TP6 | +3V2 | TestPoint:TestPoint_Pad_D1.0mm |  |  |  |  | 1
U1 | ESP32-C3-MINI-1-H4X | AQI:ESP32-C3-MINI-1 | ESP32-C3-MINI-1-H4X | Espressif | C41349510 |  | 1
U4 | TPS22917DBVR | Package_TO_SOT_SMD:SOT-23-6 | TPS22917DBVR | Texas Instruments | C2681320 |  | 1
U5,U6 | SY8089A1AAC | Package_TO_SOT_SMD:SOT-23-5 | SY8089A1AAC | Silergy | C479074 |  | 2
U7 | TPS7A2033PDBVR | Package_TO_SOT_SMD:SOT-23-5 | TPS7A2033PDBVR | Texas Instruments | C2862740 |  | 1
U8 | SCD41-D-R2 | Sensor:Sensirion_SCD4x-1EP_10.1x10.1mm_P1.25mm_EP4.8x4.8mm | SCD41-D-R2 | Sensirion |  | DNP | 1

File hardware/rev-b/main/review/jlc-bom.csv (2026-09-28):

Comment | Designator | Footprint | LCSC | MPN | Manufacturer | DNP | Qty
1uF 16V | C1,C15 | Capacitor_SMD:C_0603_1608Metric | C15849 |  |  |  | 2
10uF 25V | C2,C7,C9,C12,C16 | Capacitor_SMD:C_0805_2012Metric | C15850 |  |  |  | 5
100nF 25V | C3,C11,C14 | Capacitor_SMD:C_0603_1608Metric | C14663 |  |  |  | 3
1nF 25V | C8 | Capacitor_SMD:C_0603_1608Metric | C1588 |  |  |  | 1
22uF 10V | C10,C13 | Capacitor_SMD:C_0805_2012Metric | C45783 |  |  |  | 2
100nF 16V | C42 | Capacitor_SMD:C_0402_1005Metric | C1525 |  |  |  | 1
USBLC6-2SC6 | D1 | Package_TO_SOT_SMD:SOT-23-6 | C2827654 | USBLC6-2SC6 | TECH PUBLIC |  | 1
B5819W | D2 | Diode_SMD:D_SOD-123 | C8598 | B5819W SL | Changjiang |  | 1
USB-C / standalone | J1 | AQI:USB-C-SMD_TYPE-C-16P-L6.5 | C49287211 | TYPE-C 16P L6.5 | SHOU HAN |  | 1
BAT PWM / Dupont | J2 | Connector_PinHeader_2.54mm:PinHeader_1x02_P2.54mm_Vertical | C32713268 | HX PZ2.54-1x2P ZZ | hanxia |  | 1
SEN5x / 5V | J3 | Connector_JST:JST_GH_SM06B-GHS-TB_1x06-1MP_P1.25mm_Horizontal | C51940119 | XY-SM06B-GHS-TB | XYECO |  | 1
SEN6x / 3.3V | J4 | Connector_JST:JST_GH_SM04B-GHS-TB_1x04-1MP_P1.25mm_Horizontal | C51940118 | XY-SM04B-GHS-TB | XYECO |  | 1
TFT TOP CONTACT | J5 | Connector_FFC-FPC:TE_1-84953-0_1x10-1MP_P1.0mm_Horizontal | C3168738 | 1-84953-0 | TE Connectivity |  | 1
2.2uH SWPA4020S | L1,L2 | Inductor_SMD:L_Sunlord_SWPA4020S | C83423 | SWPA4020S2R2MT | Sunlord |  | 2
AO3400A | Q1 | Package_TO_SOT_SMD:SOT-23 | C20917 | AO3400A | Alpha & Omega |  | 1
10kR | R1-R4,R33 | Resistor_SMD:R_0603_1608Metric | C25804 |  |  |  | 5
5.1kR | R5,R6 | Resistor_SMD:R_0603_1608Metric | C23186 |  |  |  | 2
22R | R7,R8 | Resistor_SMD:R_0603_1608Metric | C23345 |  |  |  | 2
100kR | R15,R17,R19,R27 | Resistor_SMD:R_0603_1608Metric | C25803 |  |  |  | 4
100R | R16 | Resistor_SMD:R_0603_1608Metric | C22775 |  |  |  | 1
23.2kR | R18 | Resistor_SMD:R_0603_1608Metric | C49656146 |  |  |  | 1
22kR | R20 | Resistor_SMD:R_0603_1608Metric | C31850 |  |  |  | 1
4.7kR | R21,R22 | Resistor_SMD:R_0603_1608Metric | C23162 |  |  |  | 2
33R | R28 | Resistor_SMD:R_1206_3216Metric | C25375 |  |  |  | 1
1kR | R34 | Resistor_SMD:R_0603_1608Metric | C21190 |  |  |  | 1
LEFT | SW1 | Button_Switch_SMD:SW_Push_1P1T_XKB_TS-1187A | C318884 | TS-1187A-B-A-B | XKB |  | 1
OK | SW2 | Button_Switch_SMD:SW_Push_1P1T_XKB_TS-1187A | C318884 | TS-1187A-B-A-B | XKB |  | 1
RIGHT | SW3 | Button_Switch_SMD:SW_Push_1P1T_XKB_TS-1187A | C318884 | TS-1187A-B-A-B | XKB |  | 1
POWER / MSK12C02 | SW4 | Button_Switch_SMD:SW_SPDT_Shouhan_MSK12C02 | C431540 | MSK12C02 | SHOU HAN |  | 1
GND | TP1 | TestPoint:TestPoint_Pad_D1.0mm |  |  |  |  | 1
MCU_EN | TP2 | TestPoint:TestPoint_Pad_D1.0mm |  |  |  |  | 1
BOOT_GPIO9 | TP3 | TestPoint:TestPoint_Pad_D1.0mm |  |  |  |  | 1
BAT_PWM_MCU | TP4 | TestPoint:TestPoint_Pad_D1.0mm |  |  |  |  | 1
EPD_BUSY | TP5 | TestPoint:TestPoint_Pad_D1.0mm |  |  |  |  | 1
+3V2 | TP6 | TestPoint:TestPoint_Pad_D1.0mm |  |  |  |  | 1
ESP32-C3-MINI-1-H4X | U1 | AQI:ESP32-C3-MINI-1 | C41349510 | ESP32-C3-MINI-1-H4X | Espressif |  | 1
TPS22917DBVR | U4 | Package_TO_SOT_SMD:SOT-23-6 | C2681320 | TPS22917DBVR | Texas Instruments |  | 1
SY8089A1AAC | U5,U6 | Package_TO_SOT_SMD:SOT-23-5 | C479074 | SY8089A1AAC | Silergy |  | 2
TPS7A2033PDBVR | U7 | Package_TO_SOT_SMD:SOT-23-5 | C2862740 | TPS7A2033PDBVR | Texas Instruments |  | 1

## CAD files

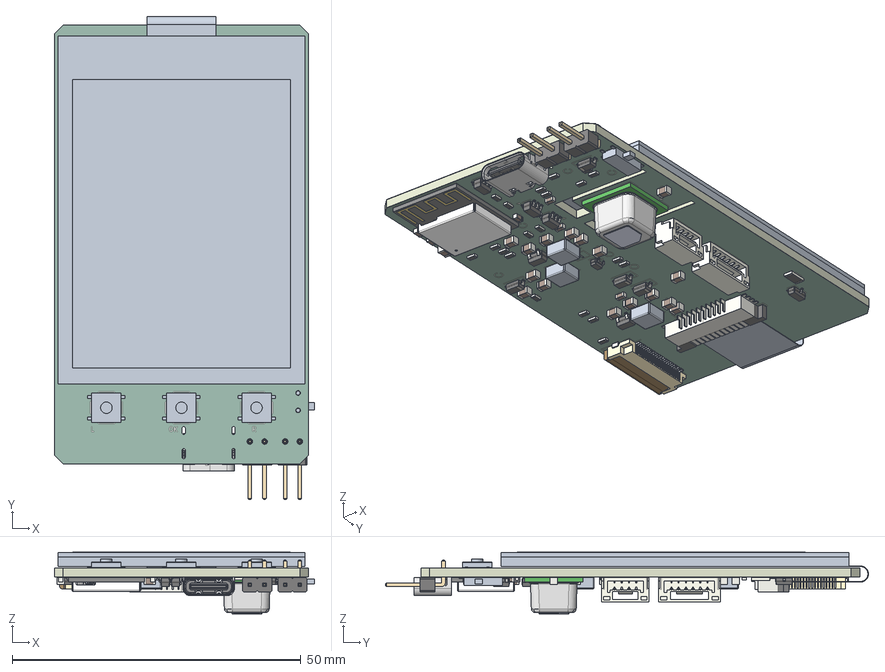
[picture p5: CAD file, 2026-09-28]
hardware/rev-b/main/aqi recorder 3d.step
45.1 x 83.6 x 10.7 mm
aqi recorder 3d 1.1.1 x 3
aqi recorder 3d 1.1.2 x 3
aqi recorder 3d 1.1.3 x 3
aqi recorder 3d 1.1.4 x 3
aqi recorder 3d 1.1.5 x 3
aqi recorder 3d 1.1.6 x 3
aqi recorder 3d 1.1.7 x 3
aqi recorder 3d 1.4.1
aqi recorder 3d 1.4.2
aqi recorder 3d 1.4.3
aqi recorder 3d 1.4.4
D_SOD-123 x 4
SOT-23-5 x 3
R_0603_1608Metric x 22
JST_GH_SM06B-GHS-TB_1x06-1MP_P1.25mm_Horizontal
C_0805_2012Metric x 18
C_0603_1608Metric x 6
SOT-323_SC-70
lock
pins
SOT-23-6 x 2
TE_1-84953-0_1x10-1MP_P1.0mm_Horizontal
Sensirion_SCD4x
PinHeader_1x02_P2.54mm_Horizontal x 2
aqi recorder 3d 1.38.1 x 3
DFN1006.STEP(2)^DFN1006.STEP(2)_Submodel-SOD882_part(2)_ DesignRootModel(2)_PCB_ESP32-C3-MINI-1_V1A(2)_PCB_ESP32-C3-MINI-1_V1A
R0201_20210301.STEP(2)^R0201_20210301.STEP(2)_Submodel-R0201_part(2)_ DesignRootModel(2)_PCB_ESP32-C3-MINI-1_V1A(2)_PCB_ESP32-C3-MINI-1_V1A x 3
placementOutline(2)^Submodel-noModelForPart_MINI-ANT-TYPED-H_ 1968823293(2)_Submodel-MINI-ANT-TYPED-H_1968823293_part(2)_ DesignRootModel(2)_PCB_ESP32-C3-MINI-1
placementOutline-0(2)^Submodel-noModelForPart_MINI-ANT-TYPED-H_ 1968823293(2)_Submodel-MINI-ANT-TYPED-H_1968823293_part(2)_ DesignRootModel(2)_PCB_ESP32-C3-MINI
placementOutline-1(2)^Submodel-noModelForPart_MINI-ANT-TYPED-H_ 1968823293(2)_Submodel-MINI-ANT-TYPED-H_1968823293_part(2)_ DesignRootModel(2)_PCB_ESP32-C3-MINI
placementOutline-2(2)^Submodel-noModelForPart_MINI-ANT-TYPED-H_ 1968823293(2)_Submodel-MINI-ANT-TYPED-H_1968823293_part(2)_ DesignRootModel(2)_PCB_ESP32-C3-MINI
placementOutline-3(2)^Submodel-noModelForPart_MINI-ANT-TYPED-H_ 1968823293(2)_Submodel-MINI-ANT-TYPED-H_1968823293_part(2)_ DesignRootModel(2)_PCB_ESP32-C3-MINI
placementOutline-4(2)^Submodel-noModelForPart_MINI-ANT-TYPED-H_ 1968823293(2)_Submodel-MINI-ANT-TYPED-H_1968823293_part(2)_ DesignRootModel(2)_PCB_ESP32-C3-MINI
placementOutline-5(2)^Submodel-noModelForPart_MINI-ANT-TYPED-H_ 1968823293(2)_Submodel-MINI-ANT-TYPED-H_1968823293_part(2)_ DesignRootModel(2)_PCB_ESP32-C3-MINI
trace_4(2)^Submodel-MINI-ANT-TYPED-H_1968823293_part(2)_ DesignRootModel(2)_PCB_ESP32-C3-MINI-1_V1A(2)_PCB_ESP32-C3-MINI-1_V1A
trace_1(2)^Submodel-MINI-ANT-TYPED-H_1968823293_part(2)_ DesignRootModel(2)_PCB_ESP32-C3-MINI-1_V1A(2)_PCB_ESP32-C3-MINI-1_V1A
C0402_20210301.STEP(2)^C0402_20210301.STEP(2)_Submodel-C0402_part(2)_ DesignRootModel(2)_PCB_ESP32-C3-MINI-1_V1A(2)_PCB_ESP32-C3-MINI-1_V1A
C0201_20210301.STEP(2)^C0201_20210301.STEP(2)_Submodel-C0201_part(2)_ DesignRootModel(2)_PCB_ESP32-C3-MINI-1_V1A(2)_PCB_ESP32-C3-MINI-1_V1A x 11
L0201_20210301.STEP(2)^L0201_20210301.STEP(2)_Submodel-L0201_part(2)_ DesignRootModel(2)_PCB_ESP32-C3-MINI-1_V1A(2)_PCB_ESP32-C3-MINI-1_V1A x 2
XTAL3225_20210301.STEP(2)^XTAL3225_20210301.STEP(2)_Submodel-XTAL3225_ part(2)_DesignRootModel(2)_PCB_ESP32-C3-MINI-1_V1A(2)_PCB_ ESP32-C3-MINI-1_V1A
ESP32-C3_20210301.STEP(2)^ESP32-C3_20210301.STEP(2)_Submodel-QFN32_0P5_ 5_part(2)_DesignRootModel(2)_PCB_ESP32-C3-MINI-1_V1A(2)_PCB_ ESP32-C3-MINI-1_V1A
uid__2428(2)^DesignRootModel(2)_PCB_ESP32-C3-MINI-1_V1A(2)_PCB_ ESP32-C3-MINI-1_V1A
ShieldBox_ESP32-C3-MINI-1_V1.0_20200901
solder_pad
aqi recorder 3d 1.48.1
aqi recorder 3d 1.48.2
aqi recorder 3d 1.48.3
aqi recorder 3d 1.48.4
aqi recorder 3d 1.48.5
aqi recorder 3d 1.48.6
aqi recorder 3d 1.48.7
aqi recorder 3d 1.48.8
aqi recorder 3d 1.48.9
aqi recorder 3d 1.48.10
aqi recorder 3d 1.48.11
R_1206_3216Metric
USB-C-SMD_TYPE-C-16P-L6.5
JST_GH_SM04B-GHS-TB_1x04-1MP_P1.25mm_Horizontal
C_0402_1005Metric
SOT-23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

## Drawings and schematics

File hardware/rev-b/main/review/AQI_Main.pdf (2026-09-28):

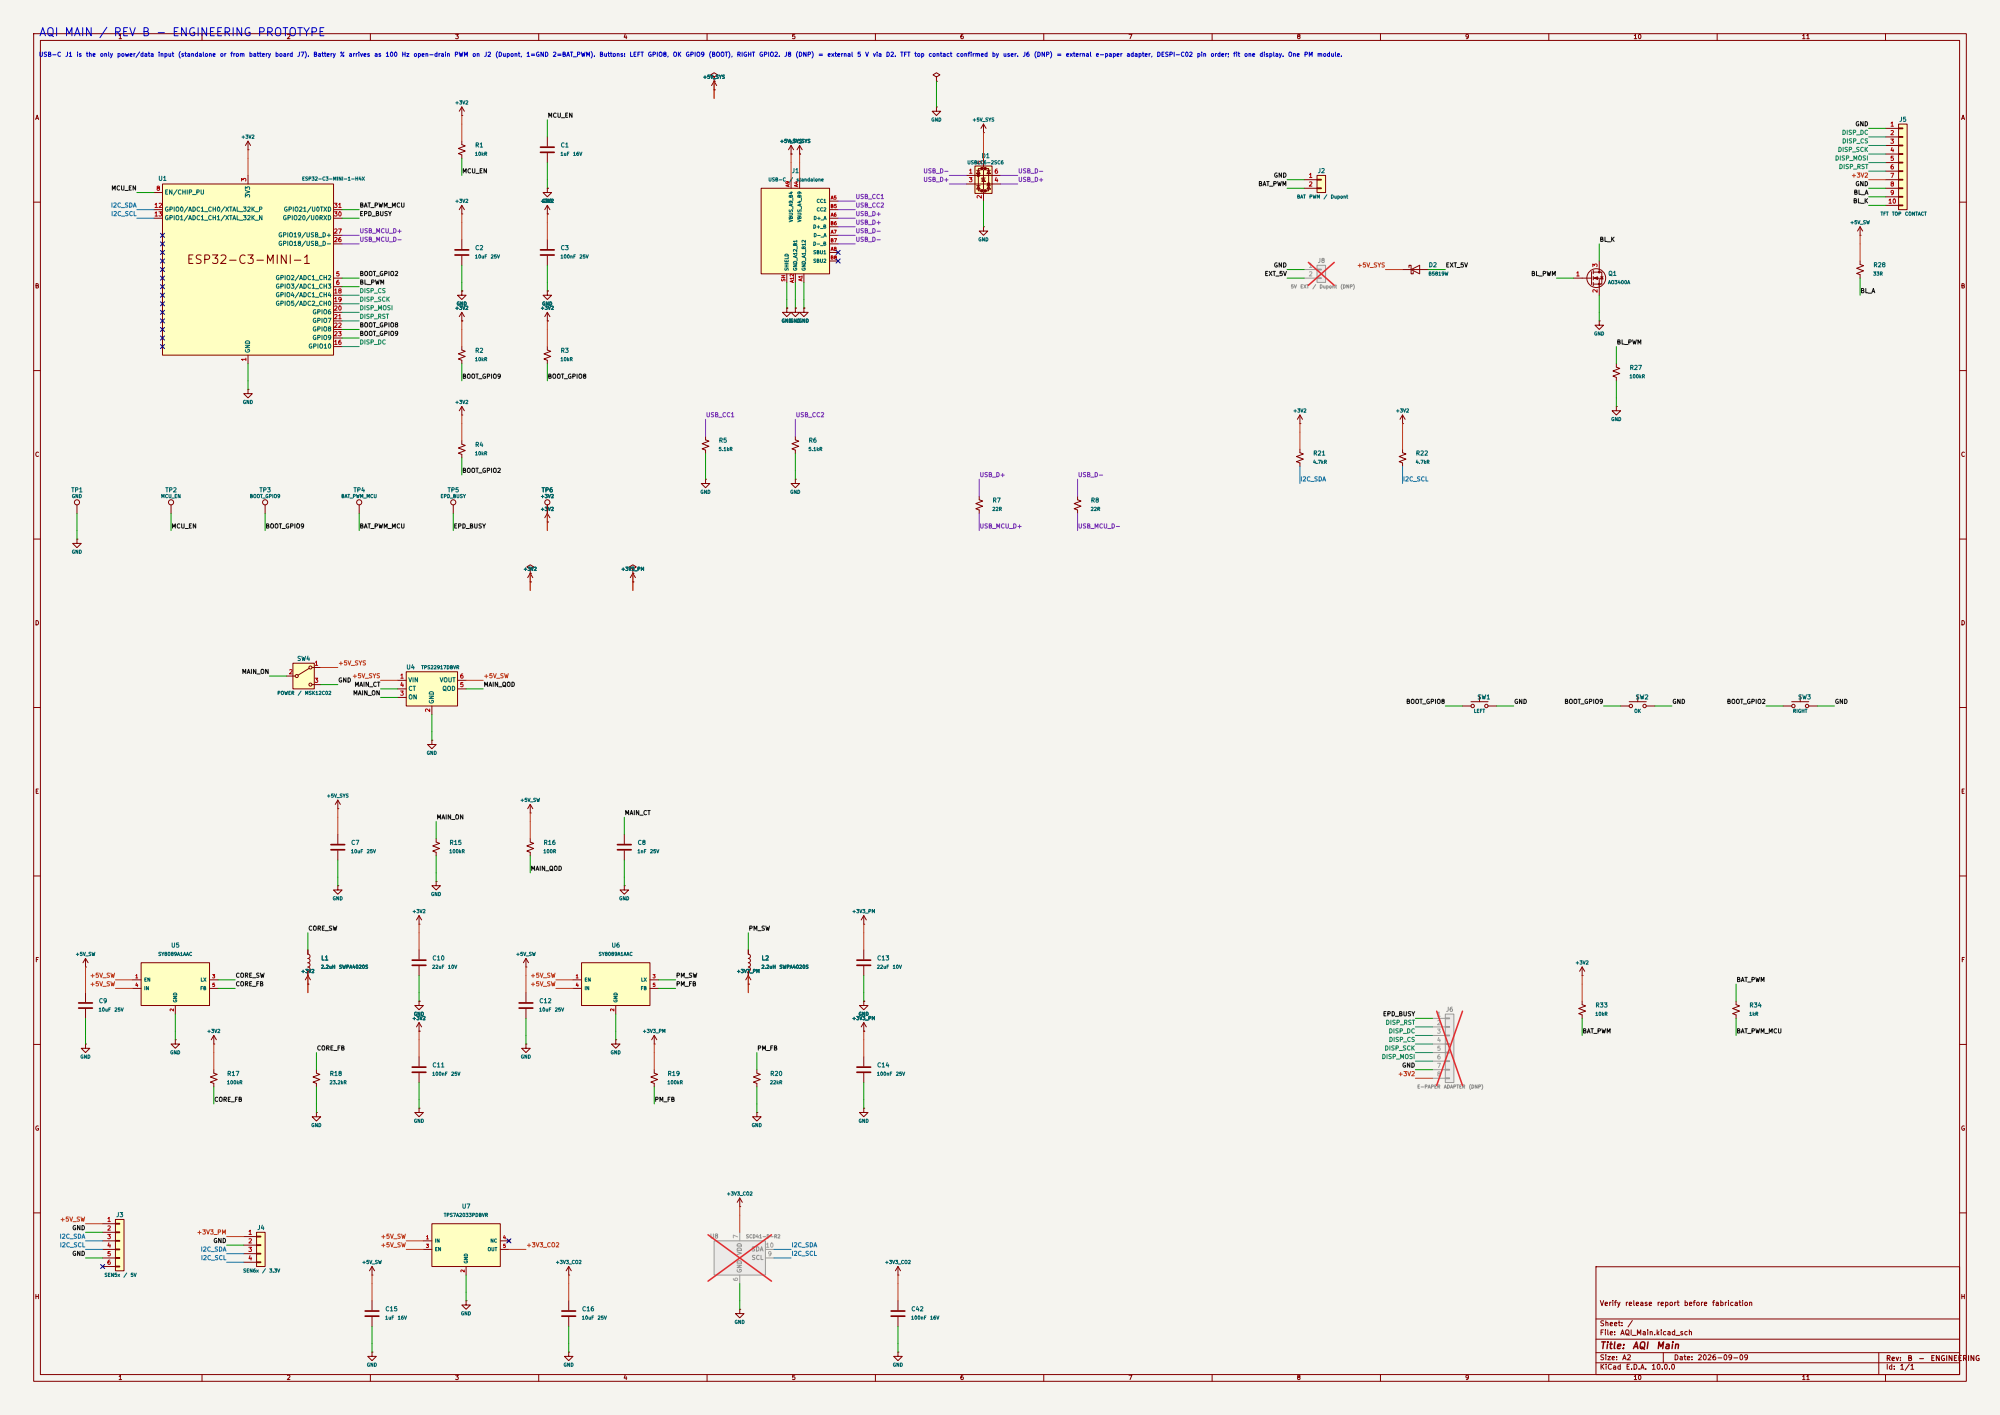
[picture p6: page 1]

USB-C J1 is the only power/data input (standalone or from battery board J7). Battery % arrives as 100 Hz open-drain PWM on J2 (Dupont, 1=GND 2=BAT_PWM). Buttons: LEFT GPIO8, OK GPIO9 (BOOT), RIGHT GPIO2. J8 (DNP) = external 5 V via D2. TFT top contact confirmed by user. J6 (DNP) = external e-paper adapter, DESPI-C02 pin order; fit one display. One PM module.

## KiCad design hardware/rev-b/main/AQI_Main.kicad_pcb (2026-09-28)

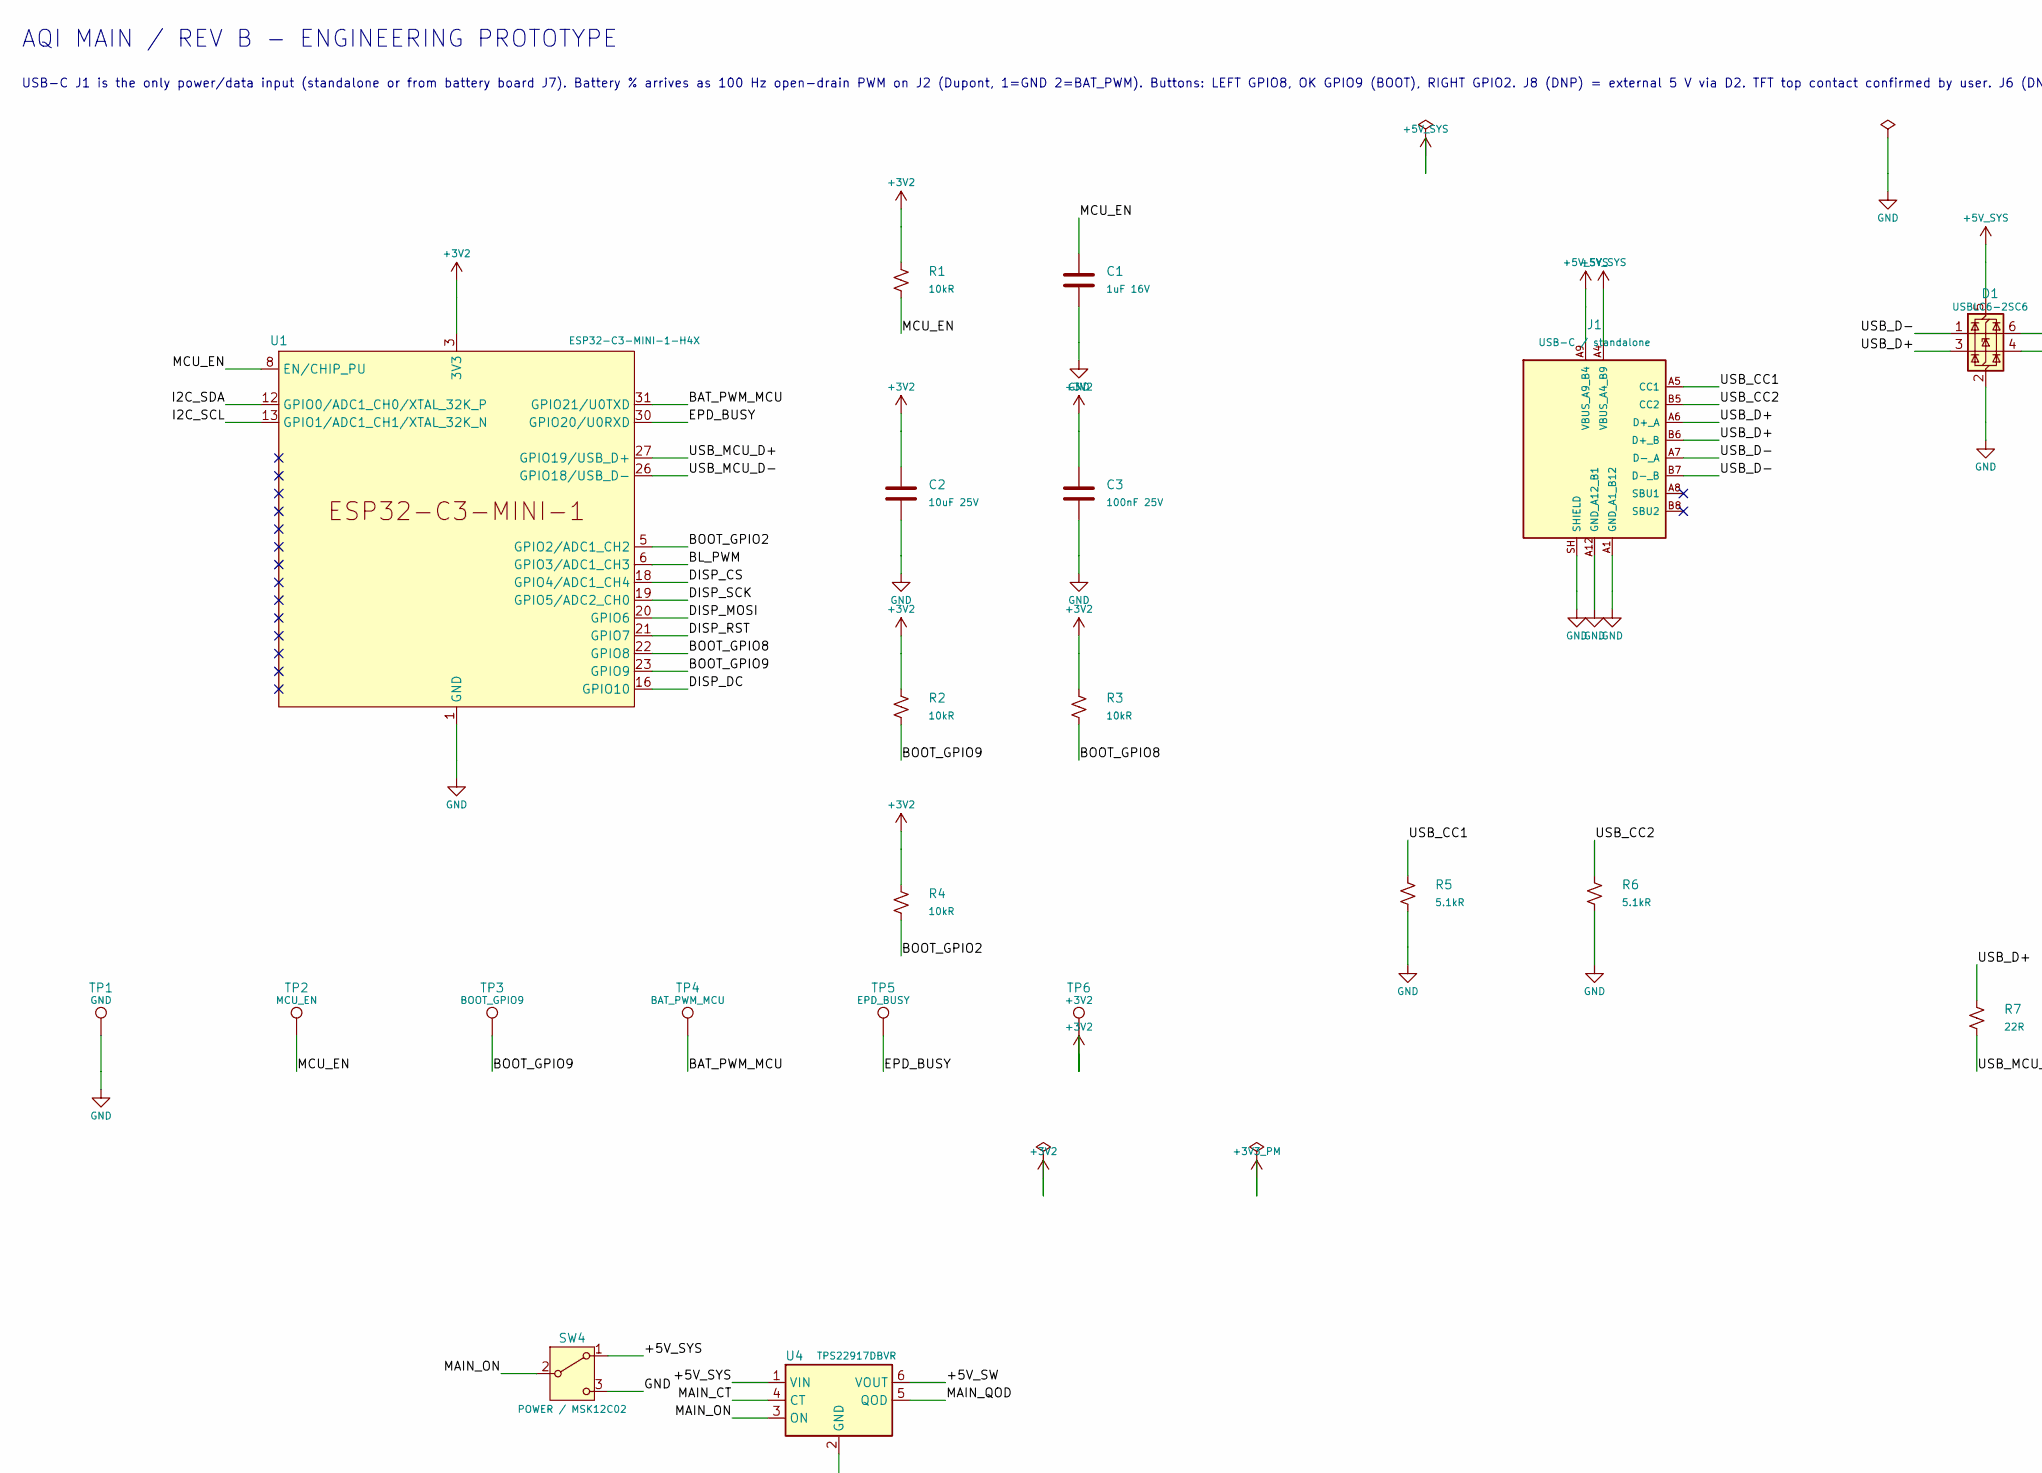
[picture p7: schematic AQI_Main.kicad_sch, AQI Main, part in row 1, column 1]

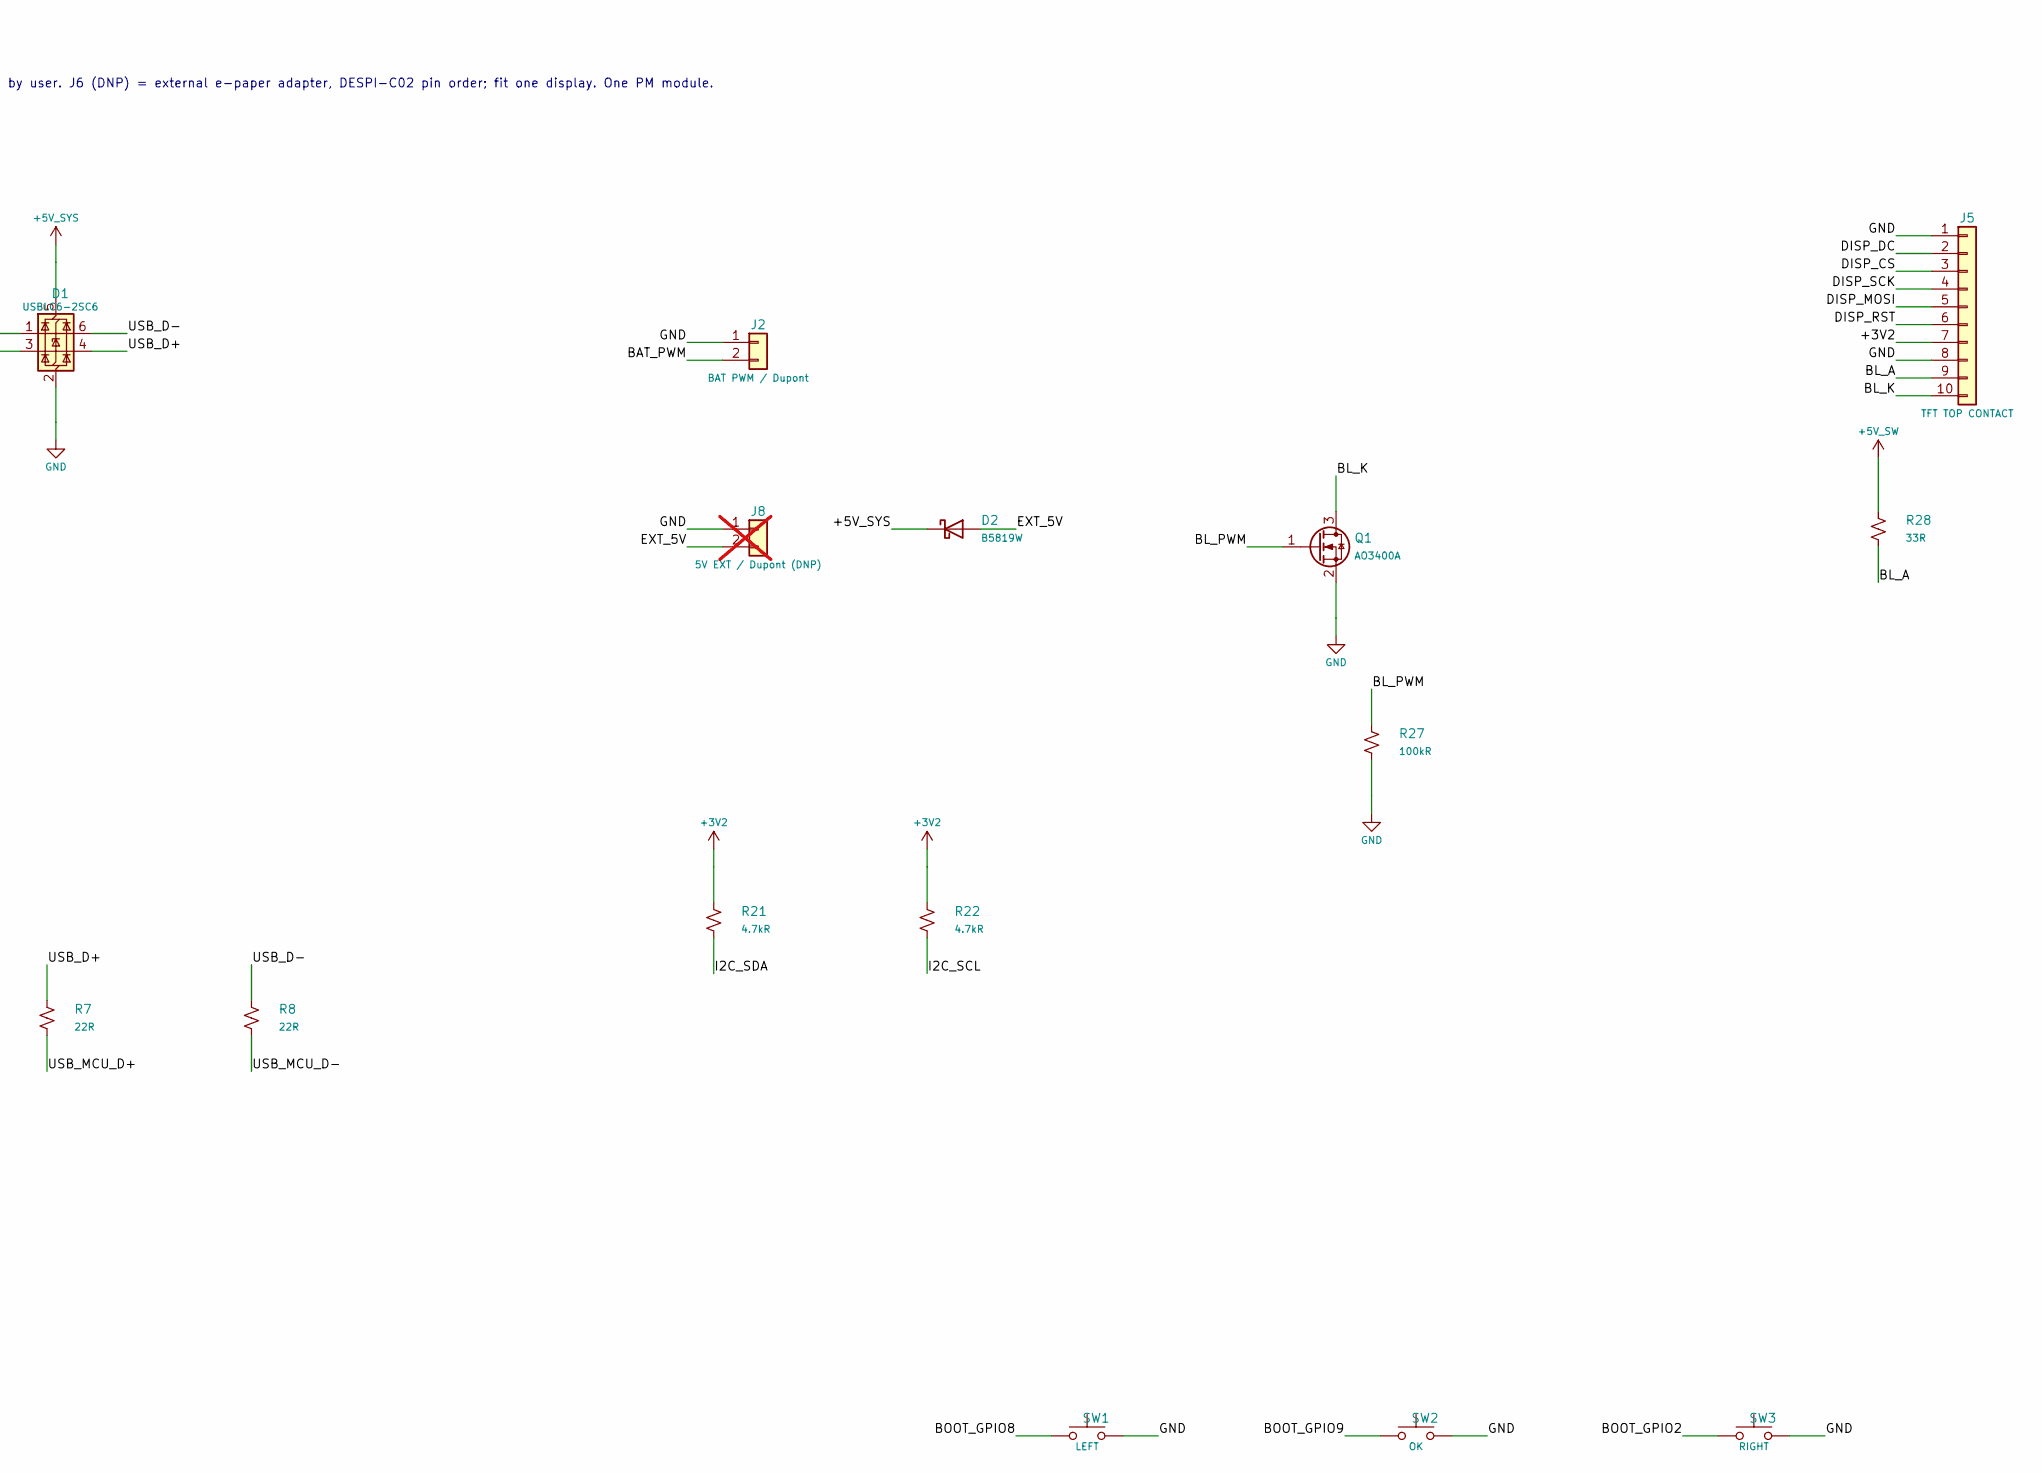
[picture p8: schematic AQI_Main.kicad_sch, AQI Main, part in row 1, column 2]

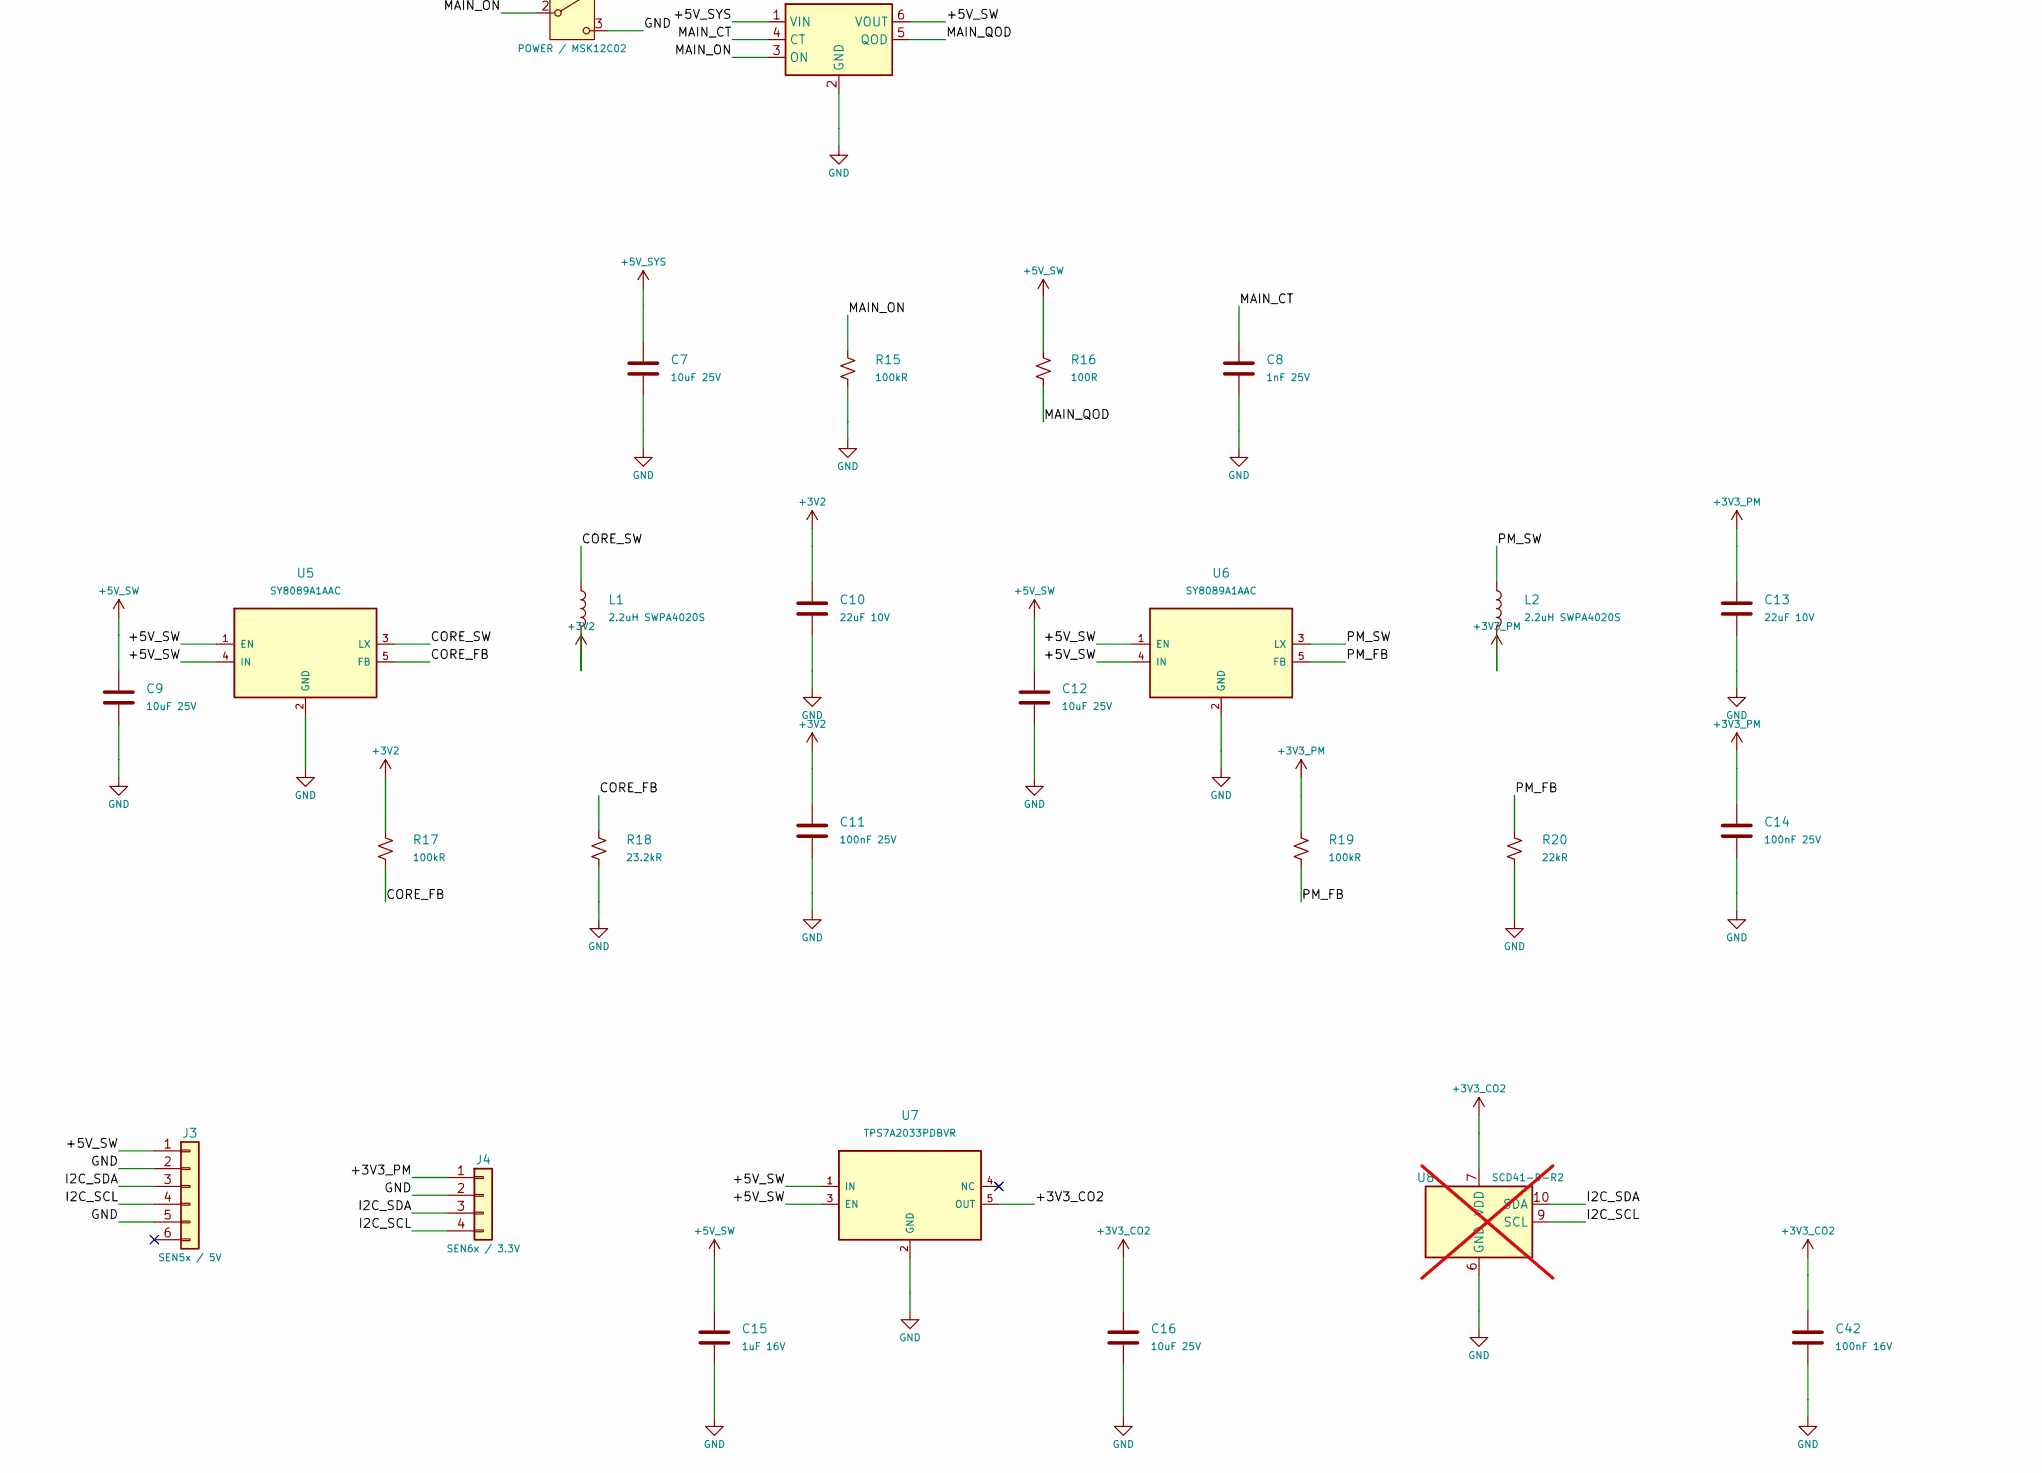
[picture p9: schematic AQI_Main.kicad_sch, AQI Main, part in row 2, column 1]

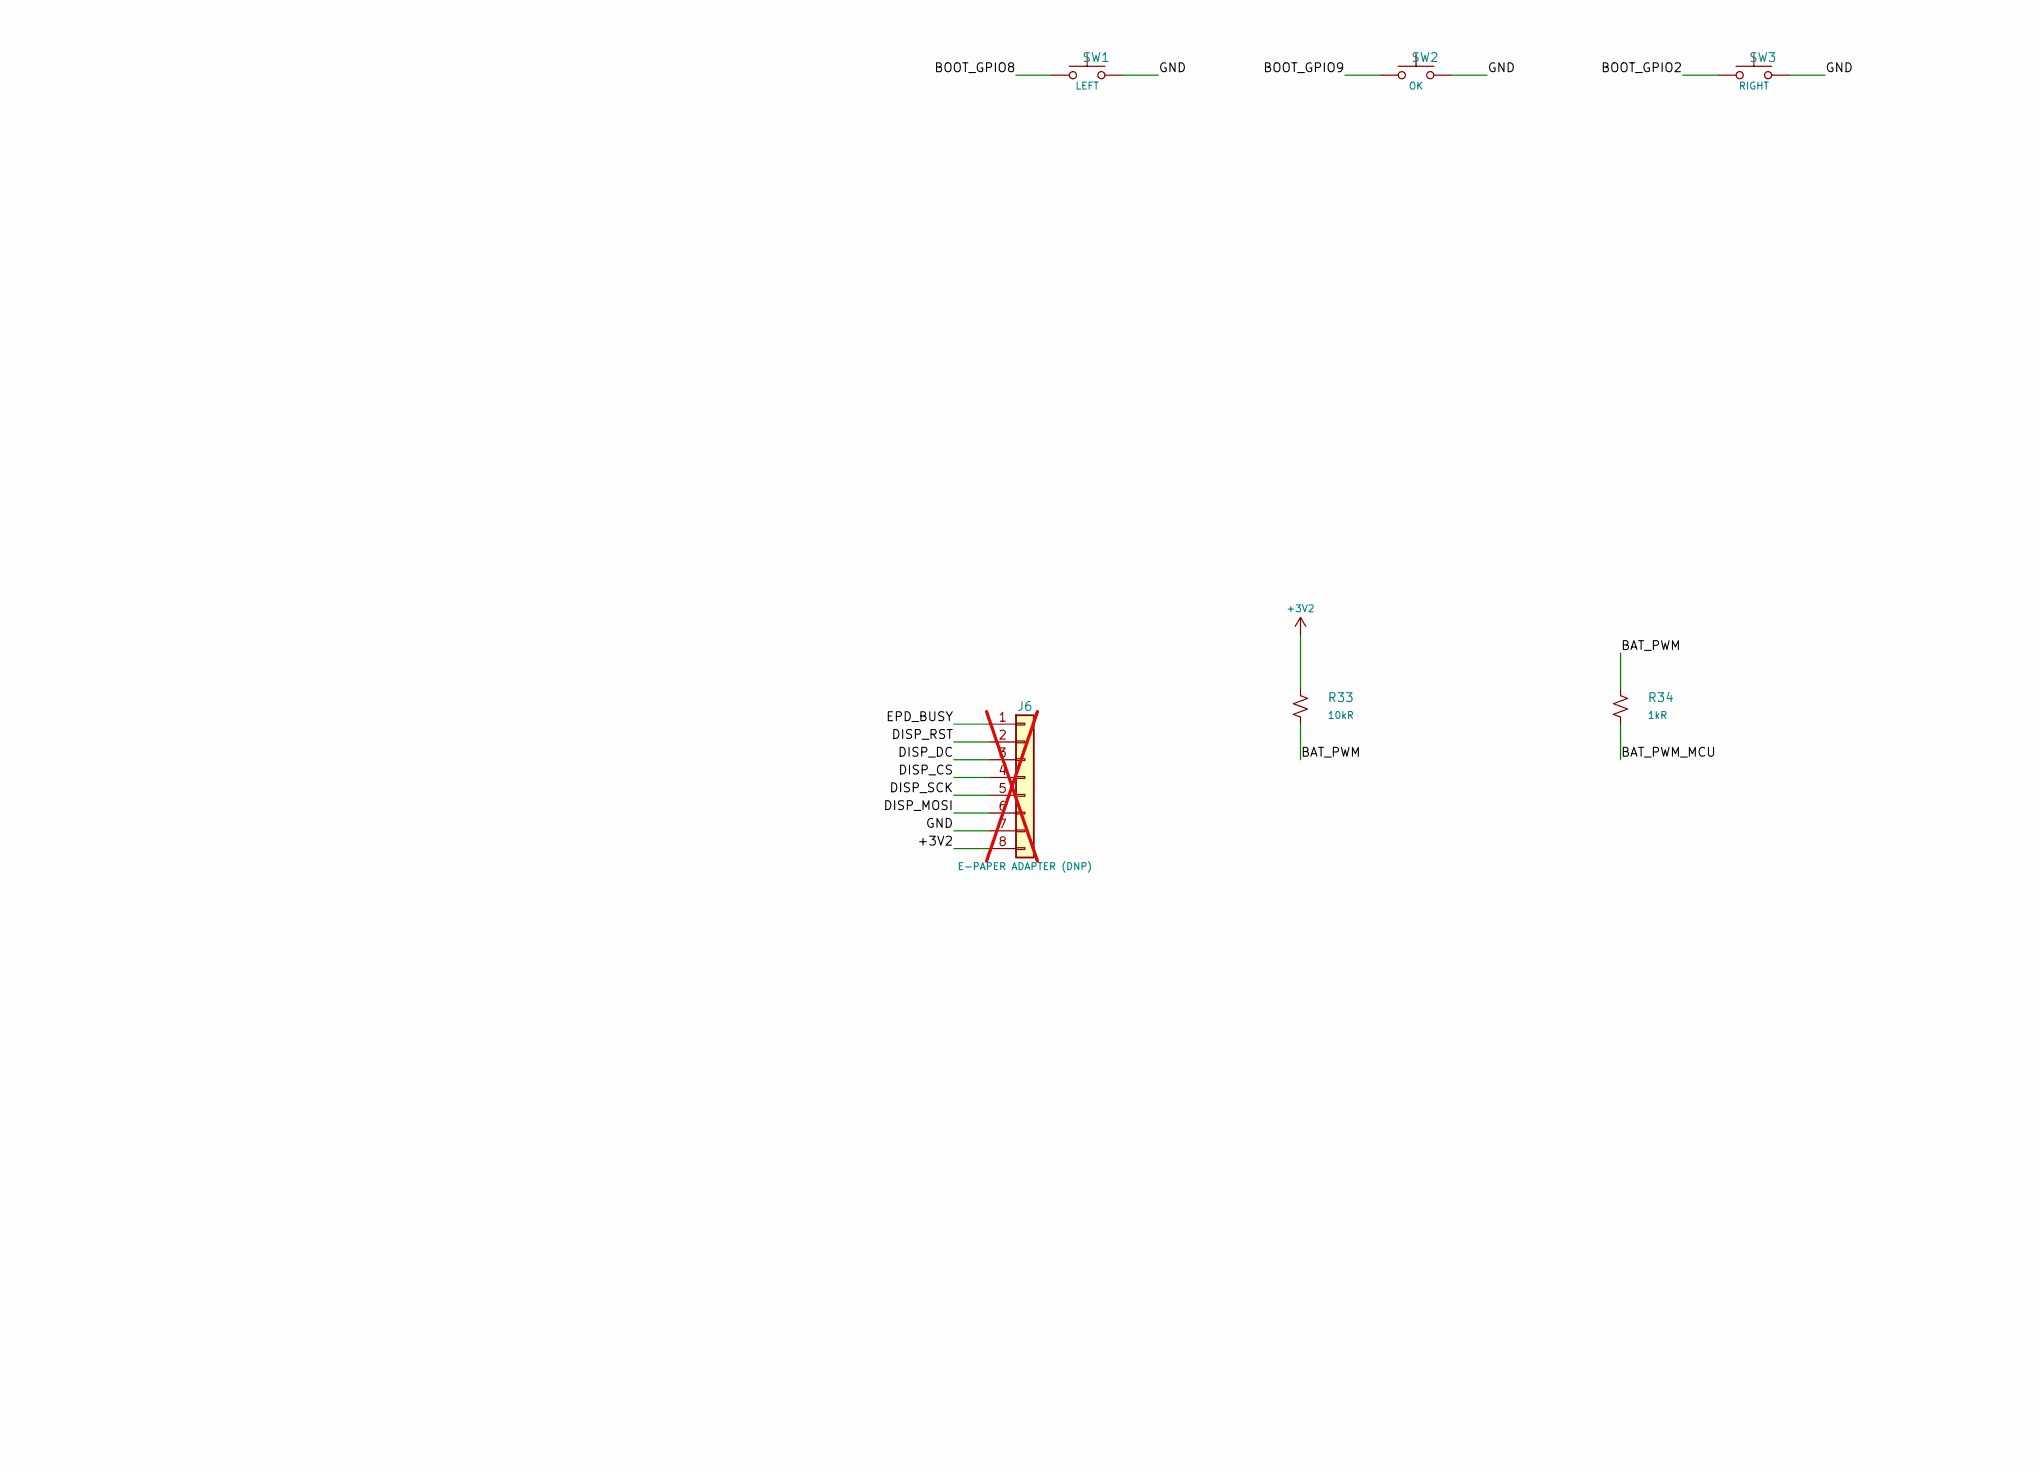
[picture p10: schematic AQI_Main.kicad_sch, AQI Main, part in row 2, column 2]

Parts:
C1, C15: 1uF 16V; C_0603_1608Metric; LCSC C15849
C2, C7, C9, C12, C16: 10uF 25V; C_0805_2012Metric; LCSC C15850
C3, C11, C14: 100nF 25V; C_0603_1608Metric; LCSC C14663
C8: 1nF 25V; C_0603_1608Metric; LCSC C1588
C10, C13: 22uF 10V; C_0805_2012Metric; LCSC C45783
C42: 100nF 16V; C_0402_1005Metric; LCSC C1525
D1: USBLC6-2SC6; SOT-23-6; MPN USBLC6-2SC6; LCSC C2827654
D2: B5819W; D_SOD-123; MPN B5819W SL; LCSC C8598
J1: USB-C / standalone; USB-C-SMD_TYPE-C-16P-L6.5; MPN TYPE-C 16P L6.5; LCSC C49287211
J2: BAT PWM / Dupont; PinHeader_1x02_P2.54mm_Vertical; MPN HX PZ2.54-1x2P ZZ; LCSC C32713268
J3: SEN5x / 5V; JST_GH_SM06B-GHS-TB_1x06-1MP_P1.25mm_Horizontal; MPN XY-SM06B-GHS-TB; LCSC C51940119
J4: SEN6x / 3.3V; JST_GH_SM04B-GHS-TB_1x04-1MP_P1.25mm_Horizontal; MPN XY-SM04B-GHS-TB; LCSC C51940118
J5: TFT TOP CONTACT; TE_1-84953-0_1x10-1MP_P1.0mm_Horizontal; MPN 1-84953-0; LCSC C3168738
J6: E-PAPER ADAPTER (DNP); PinHeader_1x08_P2.54mm_Vertical_SMD_Pin1Left; MPN 2.54mm 1x08 SMD pin header; not fitted
J8: 5V EXT / Dupont (DNP); PinHeader_1x02_P2.54mm_Vertical; MPN HX PZ2.54-1x2P ZZ; LCSC C32713268; not fitted
L1, L2: 2.2uH SWPA4020S; L_Sunlord_SWPA4020S; MPN SWPA4020S2R2MT; LCSC C83423
Q1: AO3400A; SOT-23; MPN AO3400A; LCSC C20917
R1, R2, R3, R4, R33: 10kR; R_0603_1608Metric; LCSC C25804
R5, R6: 5.1kR; R_0603_1608Metric; LCSC C23186
R7, R8: 22R; R_0603_1608Metric; LCSC C23345
R15, R17, R19, R27: 100kR; R_0603_1608Metric; LCSC C25803
R16: 100R; R_0603_1608Metric; LCSC C22775
R18: 23.2kR; R_0603_1608Metric; LCSC C49656146
R20: 22kR; R_0603_1608Metric; LCSC C31850
R21, R22: 4.7kR; R_0603_1608Metric; LCSC C23162
R28: 33R; R_1206_3216Metric; LCSC C25375
R34: 1kR; R_0603_1608Metric; LCSC C21190
SW1: LEFT; SW_Push_1P1T_XKB_TS-1187A; MPN TS-1187A-B-A-B; LCSC C318884
SW2: OK; SW_Push_1P1T_XKB_TS-1187A; MPN TS-1187A-B-A-B; LCSC C318884
SW3: RIGHT; SW_Push_1P1T_XKB_TS-1187A; MPN TS-1187A-B-A-B; LCSC C318884
SW4: POWER / MSK12C02; SW_SPDT_Shouhan_MSK12C02; MPN MSK12C02; LCSC C431540
TP1: GND; TestPoint_Pad_D1.0mm
TP2: MCU_EN; TestPoint_Pad_D1.0mm
TP3: BOOT_GPIO9; TestPoint_Pad_D1.0mm
TP4: BAT_PWM_MCU; TestPoint_Pad_D1.0mm
TP5: EPD_BUSY; TestPoint_Pad_D1.0mm
TP6: +3V2; TestPoint_Pad_D1.0mm
U1: ESP32-C3-MINI-1-H4X; ESP32-C3-MINI-1; MPN ESP32-C3-MINI-1-H4X; LCSC C41349510
U4: TPS22917DBVR; SOT-23-6; MPN TPS22917DBVR; LCSC C2681320
U5, U6: SY8089A1AAC; SOT-23-5; MPN SY8089A1AAC; LCSC C479074
U7: TPS7A2033PDBVR; SOT-23-5; MPN TPS7A2033PDBVR; LCSC C2862740
U8: SCD41-D-R2; Sensirion_SCD4x-1EP_10.1x10.1mm_P1.25mm_EP4.8x4.8mm; MPN SCD41-D-R2; not fitted

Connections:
+3V2: C2.1, C3.1, C10.1, C11.1, J5.7, J6.8, L1.2, R1.1, R2.1, R3.1, R4.1, R17.1, R21.1, R22.1, R33.1, TP6.1, U1.3 (3V3)
+3V3_CO2: C16.1, C42.1, U7.5 (OUT), U8.7 (VDD), U8.19 (VDD)
+3V3_PM: C13.1, C14.1, J4.1, L2.2, R19.1
+5V_SW: C9.1, C12.1, C15.1, J3.1, R16.1, R28.1, U4.6 (VOUT), U5.1 (EN), U5.4 (IN), U6.1 (EN), U6.4 (IN), U7.1 (IN), U7.3 (EN)
+5V_SYS: C7.1, D1.5 (VBUS), D2.1 (K), J1.A4 (VBUS_A4_B9), J1.A9 (VBUS_A9_B4), SW4.1 (A), U4.1 (VIN)
/BAT_PWM: J2.2, R33.2, R34.1
/BAT_PWM_MCU: R34.2, TP4.1, U1.31 (GPIO21/U0TXD)
/BL_A: J5.9, R28.2
/BL_K: J5.10, Q1.3 (D)
/BL_PWM: Q1.1 (G), R27.1, U1.6 (GPIO3/ADC1_CH3)
/BOOT_GPIO2: R4.2, SW3.1, U1.5 (GPIO2/ADC1_CH2)
/BOOT_GPIO8: R3.2, SW1.1, U1.22 (GPIO8)
/BOOT_GPIO9: R2.2, SW2.1, TP3.1, U1.23 (GPIO9)
/CORE_FB: R17.2, R18.1, U5.5 (FB)
/CORE_SW: L1.1, U5.3 (LX)
/DISP_CS: J5.3, J6.4, U1.18 (GPIO4/ADC1_CH4)
/DISP_DC: J5.2, J6.3, U1.16 (GPIO10)
/DISP_MOSI: J5.5, J6.6, U1.20 (GPIO6)
/DISP_RST: J5.6, J6.2, U1.21 (GPIO7)
/DISP_SCK: J5.4, J6.5, U1.19 (GPIO5/ADC2_CH0)
/EPD_BUSY: J6.1, TP5.1, U1.30 (GPIO20/U0RXD)
/EXT_5V: D2.2 (A), J8.2
/I2C_SCL: J3.4, J4.4, R22.2, U1.13 (GPIO1/ADC1_CH1/XTAL_32K_N), U8.9 (SCL)
/I2C_SDA: J3.3, J4.3, R21.2, U1.12 (GPIO0/ADC1_CH0/XTAL_32K_P), U8.10 (SDA)
/MAIN_CT: C8.1, U4.4 (CT)
/MAIN_ON: R15.1, SW4.2 (B), U4.3 (ON)
/MAIN_QOD: R16.2, U4.5 (QOD)
/MCU_EN: C1.1, R1.2, TP2.1, U1.8 (EN/CHIP_PU)
/PM_FB: R19.2, R20.1, U6.5 (FB)
/PM_SW: L2.1, U6.3 (LX)
/USB_CC1: J1.A5 (CC1), R5.1
/USB_CC2: J1.B5 (CC2), R6.1
/USB_D+: D1.3 (I/O2), D1.4 (I/O2), J1.A6 (D+_A), J1.B6 (D+_B), R7.1
/USB_D-: D1.1 (I/O1), D1.6 (I/O1), J1.A7 (D-_A), J1.B7 (D-_B), R8.1
/USB_MCU_D+: R7.2, U1.27 (GPIO19/USB_D+)
/USB_MCU_D-: R8.2, U1.26 (GPIO18/USB_D-)
GND: C1.2, C2.2, C3.2, C7.2, C8.2, C9.2, C10.2, C11.2, C12.2, C13.2, C14.2, C15.2, C16.2, C42.2, D1.2 (GND), J1.A1 (GND_A1_B12), J1.A12 (GND_A12_B1), J1.SH (SHIELD), J2.1, J3.2, J3.5, J4.2, J5.1, J5.8, J6.7, J8.1, Q1.2 (S), R5.2, R6.2, R15.2, R18.2, R20.2, R27.2, SW1.2, SW2.2, SW3.2, SW4.3 (C), TP1.1, U1.1 (GND), U1.2 (GND), U1.11 (GND), U1.14 (GND), U1.36 (GND), U1.37 (GND), U1.38 (GND), U1.39 (GND), U1.40 (GND), U1.41 (GND), U1.42 (GND), U1.43 (GND), U1.44 (GND), U1.45 (GND), U1.46 (GND), U1.47 (GND), U1.48 (GND), U1.49 (GND), U1.50 (GND), U1.51 (GND), U1.52 (GND), U1.53 (GND), U4.2 (GND), U5.2 (GND), U6.2 (GND), U7.2 (GND), U8.6 (GND), U8.20 (GND), U8.21 (GND)

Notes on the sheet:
AQI MAIN / REV B - ENGINEERING PROTOTYPE
USB-C J1 is the only power/data input (standalone or from battery board J7). Battery % arrives as 100 Hz open-drain PWM on J2 (Dupont, 1=GND 2=BAT_PWM). Buttons: LEFT GPIO8, OK GPIO9 (BOOT), RIGHT GPIO2. J8 (DNP) = external 5 V via D2. TFT top contact confirmed by user. J6 (DNP) = external e-paper 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

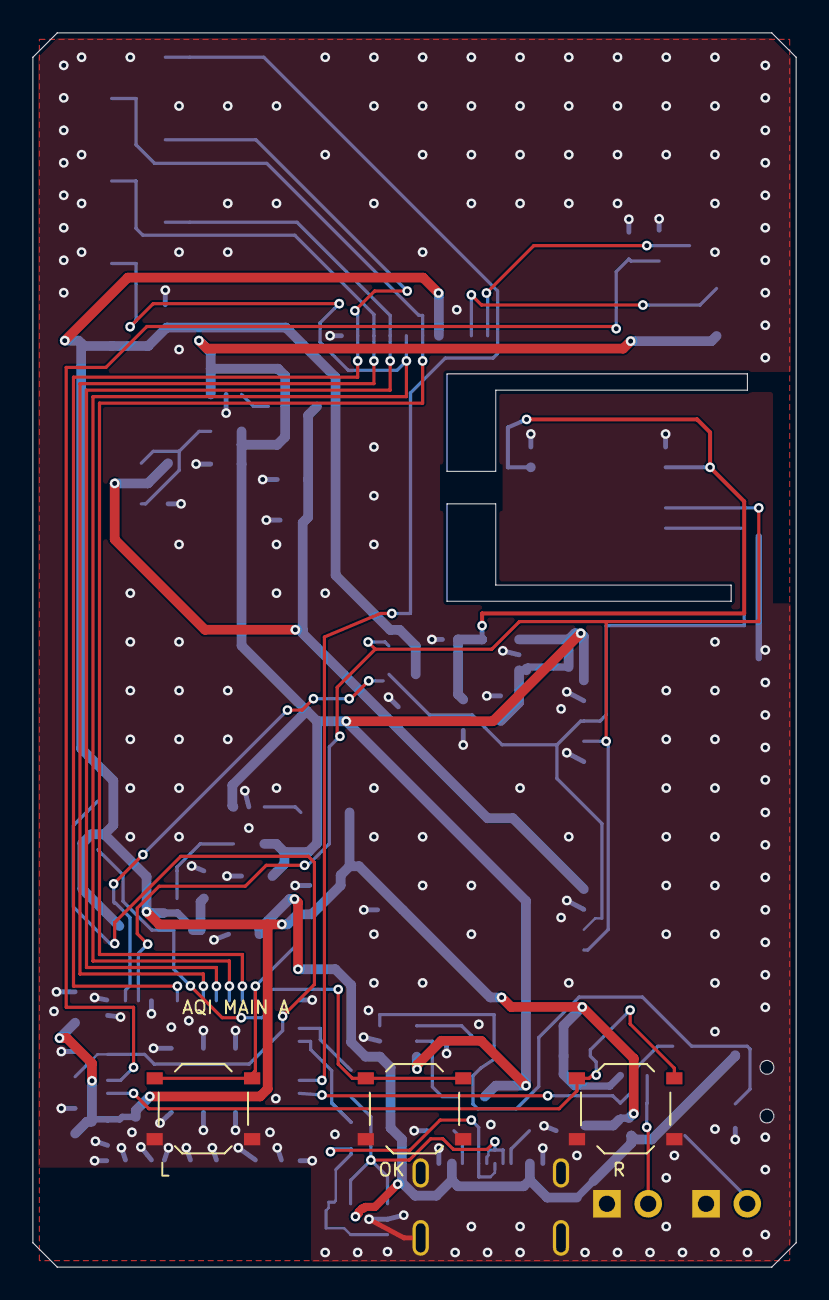
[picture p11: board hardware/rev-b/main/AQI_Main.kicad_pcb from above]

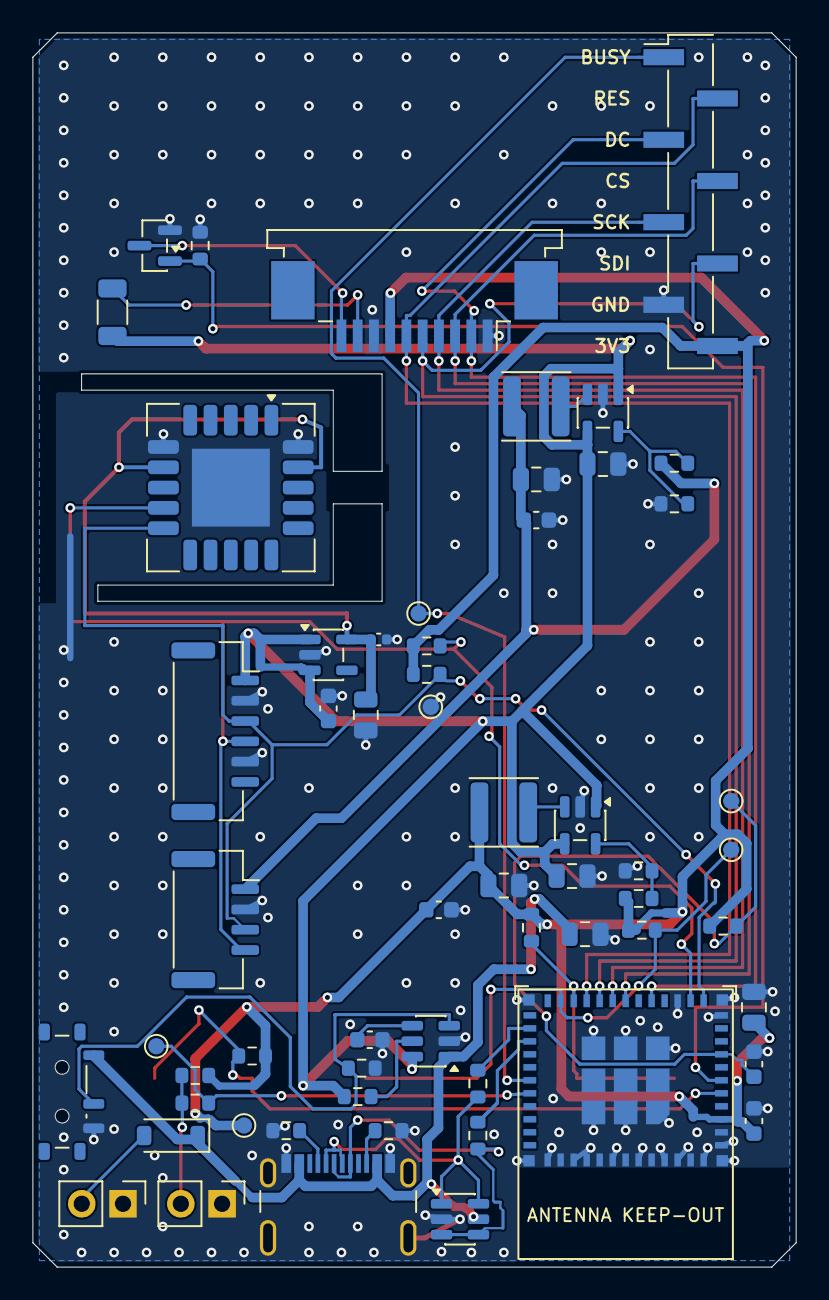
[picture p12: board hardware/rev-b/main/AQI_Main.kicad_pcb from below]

Board: 2 copper layers, 47.0 x 76.0 mm, 63 parts (59 on the bottom side), 37 nets.

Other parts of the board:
DS1: TFT 2.4in ST7789 (panel); TFT_2.4in_ST7789_10P_Panel

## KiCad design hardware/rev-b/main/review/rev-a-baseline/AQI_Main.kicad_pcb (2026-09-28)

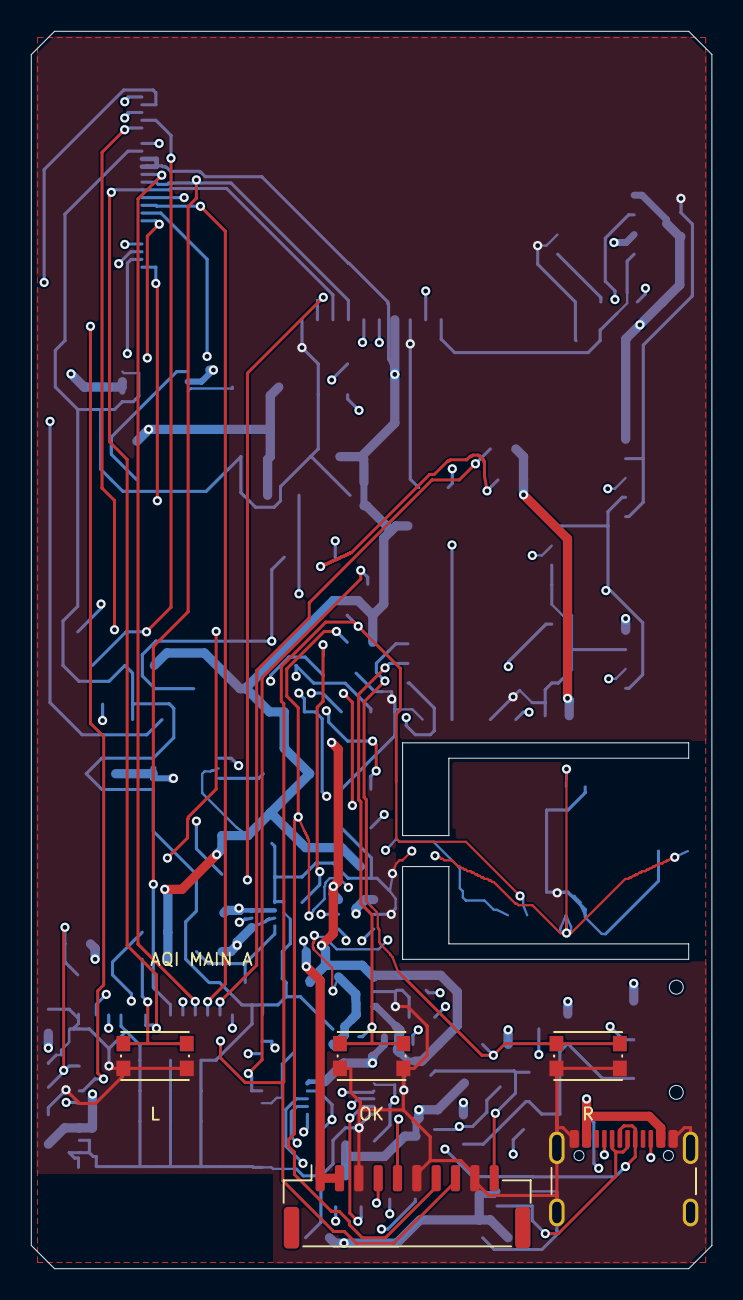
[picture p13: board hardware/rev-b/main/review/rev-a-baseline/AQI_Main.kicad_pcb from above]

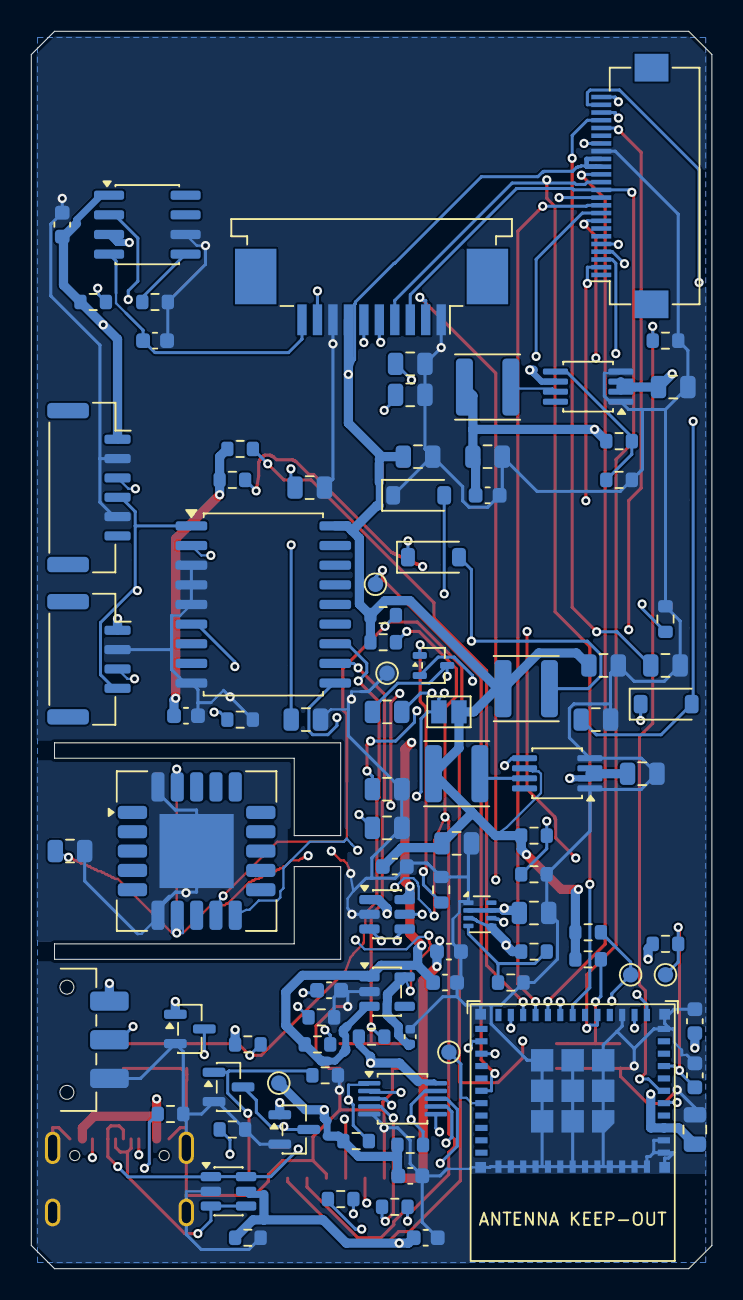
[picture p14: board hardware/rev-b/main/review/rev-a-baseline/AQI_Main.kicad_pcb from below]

Board: 4 copper layers, 44.0 x 80.0 mm, 100 parts (95 on the bottom side), 62 nets.

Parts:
C1, C4, C6, C15: 1uF 16V; C_0603_1608Metric
C2, C7, C9, C12, C16: 10uF 25V; C_0805_2012Metric
C3, C5, C11, C14, C17, C18: 100nF 25V; C_0603_1608Metric
C8: 1nF 25V; C_0603_1608Metric
C10, C13: 22uF 10V; C_0805_2012Metric
C19: 470nF 16V; C_0603_1608Metric
C30, C31: 4.7uF 50V; C_0805_2012Metric
C32, C33, C34, C35, C36, C38, C39, C40, C41: 1uF 50V; C_0805_2012Metric
C42: 100nF 16V; C_0402_1005Metric
D1: USBLC6-2SC6; SOT-23-6
D10, D11, D12: MBR0530; D_SOD-123
J1: USB-C / standalone; USB_C_Receptacle_GCT_USB4105-xx-A_16P_TopMnt_Horizontal
J2: BATTERY / JST GH; JST_GH_SM10B-GHS-TB_1x10-1MP_P1.25mm_Horizontal
J3: SEN5x / 5V; JST_GH_SM06B-GHS-TB_1x06-1MP_P1.25mm_Horizontal
J4: SEN6x / 3.3V; JST_GH_SM04B-GHS-TB_1x04-1MP_P1.25mm_Horizontal
J5: TFT TOP CONTACT; TE_1-84953-0_1x10-1MP_P1.0mm_Horizontal
J6: GDEY037T03; Hirose_FH12-24S-0.5SH_1x24-1MP_P0.50mm_Horizontal
J7: EPD BS high override; SolderJumper-2_P1.3mm_Open_Pad1.0x1.5mm
L1, L2: 2.2uH SWPA4020S; L_Sunlord_SWPA4020S
L3: 10uH 1A; L_Sunlord_SWPA4020S
Q1, Q2, Q4: AO3400A; SOT-23
Q3: Si1308EDL; SOT-323_SC-70
R1, R2, R3, R4, R23, R24, R25: 10kR; R_0603_1608Metric
R5, R6: 5.1kR; R_0603_1608Metric
R7, R8: 22R; R_0603_1608Metric
R9, R10: 47kR; R_0603_1608Metric
R11, R30: 1MR; R_0603_1608Metric
R12, R14, R15, R18, R20, R27: 100kR; R_0603_1608Metric
R13: 301kR; R_0603_1608Metric
R16: 100R; R_0603_1608Metric
R17: 300kR; R_0603_1608Metric
R19: 316kR; R_0603_1608Metric
R21, R22: 4.7kR; R_0603_1608Metric
R26: 1.5R; R_0603_1608Metric
R28, R32: 0R; R_0603_1608Metric
R31: 0.47R; R_0603_1608Metric
SW1: LEFT; SW_Push_1P1T_NO_CK_KMR2
SW2: OK; SW_Push_1P1T_NO_CK_KMR2
SW3: RIGHT; SW_Push_1P1T_NO_CK_KMR2
SW4: POWER / JS102011SAQN; SW_SPDT_CK_JS102011SAQN
TP1: GND; TestPoint_Pad_D1.0mm
TP2: MCU_EN; TestPoint_Pad_D1.0mm
TP3: BOOT_GPIO9; TestPoint_Pad_D1.0mm
TP4: UART_TX; TestPoint_Pad_D1.0mm
TP5: EPD_BUSY; TestPoint_Pad_D1.0mm
TP6: +3V2; TestPoint_Pad_D1.0mm
U1: ESP32-C3-MINI-1-H4; ESP32-C3-MINI-1
U2: TS3USB30EDGSR; TSSOP-10_3x3mm_P0.5mm
U3: TPS2116DRLR; SOT-583-8
U4: TPS22917DBVR; SOT-23-6
U5, U6: TPS62160DGKR; MSOP-8_3x3mm_P0.65mm
U7: TPS7A2033PDBVR; SOT-23-5
U8: SCD41-D-R2; Sensirion_SCD4x-1EP_10.1x10.1mm_P1.25mm_EP4.8x4.8mm
U9: MCP23008-E/SO; SOIC-18W_7.5x11.6mm_P1.27mm
U10: STCS05ADR; SOIC-8_3.9x4.9mm_P1.27mm

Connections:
+3V2: C2.1, C3.1, C5.1, C10.1, C11.1, C17.1, C30.1, C35.1, J5.7, J6.15, J6.16, J7.2, L1.2, L3.1, R1.1, R2.1, R3.1, R4.1, R9.1, R10.1, R17.1, R21.1, R22.1, R23.1, R24.1, R25.1, TP6.1, U1.3, U2.10, U5.6, U9.18, U10.3
+3V3_CO2: C16.1, C42.1, U7.5, U8.7, U8.19
+3V3_PM: C13.1, C14.1, J4.1, L2.2, R19.1, U6.6
+5V_INT: C6.1, J2.1, J2.2, U3.6
+5V_SW: C9.1, C12.1, C15.1, C18.1, J3.1, R16.1, R28.1, U4.6, U5.2, U5.3, U6.2, U6.3, U7.1, U7.3, U10.1
+5V_SYS: C7.1, SW4.1, U3.2, U3.7, U4.1
+5V_USB: C4.1, D1.5, J1.A4, J1.A9, J1.B4, J1.B9, Q1.1, Q2.1, R12.1, R13.1, U3.3, U3.5
/BL_A: J5.9, R28.2
/BL_FB: R26.1, U10.5
/BL_K: C19.1, J5.10, U10.4
/BL_PWM: R27.1, U1.6, U10.2
/BOOT_GPIO2: R4.2, U1.5
/BOOT_GPIO8: R3.2, U1.22
/BOOT_GPIO9: R2.2, TP3.1, U1.23
/BUTTON_LEFT: R23.2, SW1.1, U9.10
/BUTTON_OK: R24.2, SW2.1, U9.11
/BUTTON_RIGHT: R25.2, SW3.1, U9.12
/CORE_FB: R17.2, R18.1, U5.5
/CORE_SW: L1.1, U5.7
/DISP_CS: J5.3, J6.12, U1.16
/DISP_DC: J5.2, J6.11, U1.19
/DISP_MOSI: J5.5, J6.14, U1.20
/DISP_RST: J5.6, J6.10, U1.21
/DISP_SCK: J5.4, J6.13, U1.18
/EPD_BOOST_SW: C31.1, D12.2, L3.2, Q3.3
/EPD_BS: J6.8, J7.1, R32.1
/EPD_BUSY: J6.9, TP5.1, U1.30
/EPD_GDR: J6.2, Q3.1, R30.1
/EPD_NEG_PUMP: C31.2, D10.1, D11.2
/EPD_PREVGH: C34.1, D12.1, J6.21
/EPD_PREVGL: C39.1, D10.2, J6.23
/EPD_RESE: J6.3, Q3.2, R31.1
/EPD_VCOM: C41.1, J6.24
/EPD_VDD: C36.1, J6.18
/EPD_VGH: C33.1, J6.5
/EPD_VGL: C32.1, J6.4
/EPD_VSH1: C38.1, J6.20
/EPD_VSL: C40.1, J6.22
/I2C_SCL: J2.8, J3.4, J4.4, R22.2, U1.13, U8.9, U9.1
/I2C_SDA: J2.7, J3.3, J4.3, R21.2, U1.12, U8.10, U9.2
/INT_HOST_PRESENT: J2.10, Q4.1, R11.1
/MAIN_CT: C8.1, U4.4
/MAIN_ON: R15.1, SW4.2, U4.3
/MAIN_QOD: R16.2, U4.5
/MCU_EN: C1.1, R1.2, TP2.1, U1.8, U9.6
/PM_FB: R19.2, R20.1, U6.5
/PM_SW: L2.1, U6.7
/PWR_PR1: R13.2, R14.1, U3.4
/UART_TX: TP4.1, U1.31
/USB_CC1: J1.A5, R5.1
/USB_CC2: J1.B5, R6.1
/USB_INT_D+: J2.5, U2.3
/USB_INT_D-: J2.4, U2.7
/USB_LOCAL_D+: D1.1, D1.6, J1.A6, J1.B6, U2.2
/USB_LOCAL_D-: D1.3, D1.4, J1.A7, J1.B7, U2.8
/USB_MCU_D+: R7.2, U1.27
/USB_MCU_D-: R8.2, U1.26
/USB_OE_N: Q2.3, Q4.3, R10.2, U2.9
/USB_SEL_INT: Q1.3, R9.2, U2.1
/USB_SWITCH_D+: R7.1, U2.4
/USB_SWITCH_D-: R8.1, U2.6
GND: C1.2, C2.2, C3.2, C4.2, C5.2, C6.2, C7.2, C8.2, C9.2, C10.2, C11.2, C12.2, C13.2, C14.2, C15.2, C16.2, C17.2, C18.2, C19.2, C30.2, C32.2, C33.2, C34.2, C35.2, C36.2, C38.2, C39.2, C40.2, C41.2, C42.2, D1.2, D11.1, J1.A1, J1.A12, J1.B1, J1.B12, J1.SH, J2.3, J2.6, J2.9, J3.2, J3.5, J4.2, J5.1, J5.8, J6.17, Q1.2, Q2.2, Q4.2, R5.2, R6.2, R11.2, R12.2, R14.2, R15.2, R18.2, R20.2, R26.2, R27.2, R30.2, R31.2, R32.2, SW1.2, SW2.2, SW3.2, SW4.3, TP1.1, U1.1, U1.2, U1.11, U1.14, U1.36, U1.37, U1.38, U1.39, U1.40, U1.41, U1.42, U1.43, U1.44, U1.45, U1.46, U1.47, U1.48, U1.49, U1.50, U1.51, U1.52, U1.53, U2.5, U3.1, U4.2, U5.1, U5.4, U6.1, U6.4, U7.2, U8.6, U8.20, U8.21, U9.3, U9.4, U9.5, U9.9, U10.6

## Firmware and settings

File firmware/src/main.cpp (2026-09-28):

/**
 * Portable AQI Recorder — V3 main board (Rev B) firmware
 * ESP32-C3-MINI-1 + SEN5x or SEN6x + optional SCD4x + 2.4" ST7789 TFT
 *
 * - Detects the particulate sensor at boot: SEN50/54/55 on J3 or SEN63C/65/66/68 on J4,
 *   plus an SCD40/SCD41/SCD43 on the CO2 island if one has been fitted.
 * - Home screen with AQI, PM, CO2, VOC, NOx, temperature and humidity; full-screen charts.
 * - Three buttons: LEFT/RIGHT move the selection, OK opens/closes a chart,
 *   holding OK starts/stops recording. OK on the gear cycles the backlight brightness.
 * - Streams samples over BLE (same service as V2, so the V2 web app works).
 * - Reads battery % from the battery board (PWM on J2 -> GPIO21).
 * - Logs over native USB (the same USB-C port used for programming).
 */

#include <Arduino.h>
#include <NimBLEDevice.h>
#include <Preferences.h>
#include <Wire.h>

#include "BatteryPwmReader.h"
#include "buttons.h"
#include "data_buffer.h"
#include "display.h"
#include "sensors.h"

// ---------------------------------------------------------------------------
//  Board pins (main board Rev B; see hardware/rev-b/main/README.md)
// ---------------------------------------------------------------------------

static constexpr uint8_t PIN_I2C_SDA = 0;
static constexpr uint8_t PIN_I2C_SCL = 1;
static constexpr uint8_t PIN_BAT_PWM = 21;   // through R34; R33 pull-up. Never start UART0 TX here.
// Display (DC 10, CS 4, SCK 5, MOSI 6, RST 7) is set in platformio.ini; backlight GPIO3 in display.cpp.
// GPIO20 is the e-paper BUSY input on J6 (e-paper builds only; not used by this TFT firmware).

// ---------------------------------------------------------------------------
//  State
// ---------------------------------------------------------------------------

static const unsigned long MEASUREMENT_INTERVAL_MS = 1000;
static const unsigned long DISPLAY_UPDATE_INTERVAL_MS = 33;
static unsigned long lastMeasurementMs = 0;
static unsigned long lastDisplayUpdateMs = 0;

static ScreenMode screenMode = ScreenMode::HOME;
static DataField cursorField = DataField::AQI;
static const DataField navSequence[] = {
  DataField::AQI, DataField::PM2_5, DataField::CO2, DataField::VOC_INDEX,
  DataField::NOX_INDEX, DataField::TEMPERATURE, DataField::HUMIDITY, DataField::SETTINGS
};
static constexpr int NAV_COUNT = sizeof(navSequence) / sizeof(navSequence[0]);
static int navIndex = 0;

static SensorSample latestSample = {};
static unsigned long recordingStartMs = 0;
static DataBuffer dataBuffer;

static const uint8_t BRIGHTNESS_LEVELS[] = {100, 70, 40, 15};
static uint8_t brightnessIndex = 0;
static Preferences prefs;

static int batteryPercent = -1;

// ---------------------------------------------------------------------------
//  US EPA AQI (unchanged from V2)
// ---------------------------------------------------------------------------

static int calcAQILinear(float Ih, float Il, float Ch, float Cl, float C) {
  float value = ((Ih - Il) / (Ch - Cl)) * (C - Cl) + Il;
  // Preserve the uint16_t sample/BLE format without wrapping extreme values.
  return value >= 65535.0f ? 65535 : (int)round(value);
}

int aqiFromPM25(float pm25) {
  if (!isfinite(pm25) || pm25 < 0.0f) return -1;
  pm25 = floorf(pm25 * 10.0f) / 10.0f;
  if (pm25 <= 9.0f)   return calcAQILinear(50, 0, 9.0f, 0.0f, pm25);
  if (pm25 <= 35.4f)  return calcAQILinear(100, 51, 35.4f, 9.1f, pm25);
  if (pm25 <= 55.4f)  return calcAQILinear(150, 101, 55.4f, 35.5f, pm25);
  if (pm25 <= 125.4f) return calcAQILinear(200, 151, 125.4f, 55.5f, pm25);
  if (pm25 <= 225.4f) return calcAQILinear(300, 201, 225.4f, 125.5f, pm25);
  // EPA: above 500, continue the 301–500 band's slope.
  return calcAQILinear(500, 301, 325.4f, 225.5f, pm25);
}

int aqiFromPM10(float pm10) {
  if (!isfinite(pm10) || pm10 < 0.0f) return -1;
  pm10 = floorf(pm10);
  if (pm10 <= 54.0f)  return calcAQILinear(50, 0, 54.0f, 0.0f, pm10);
  if (pm10 <= 154.0f) return calcAQILinear(100, 51, 154.0f, 55.0f, pm10);
  if (pm10 <= 254.0f) return calcAQILinear(150, 101, 254.0f, 155.0f, pm10);
  if (pm10 <= 354.0f) return calcAQILinear(200, 151, 354.0f, 255.0f, pm10);
  if (pm10 <= 424.0f) return calcAQILinear(300, 201, 424.0f, 355.0f, pm10);
  return calcAQILinear(500, 301, 604.0f, 425.0f, pm10);
}

const char *aqiCategory(int aqi) {
  if (aqi <= 50)  return "Good";
  if (aqi <= 100) return "Moderate";
  if (aqi <= 150) return "Unhealthy for Sensitive Groups";
  if (aqi <= 200) return "Unhealthy";
  if (aqi <= 300) return "Very Unhealthy";
  return "Hazardous";
}

// ---------------------------------------------------------------------------
//  BLE (V2 service and packet layout; CO2 and battery appended at the end)
// ---------------------------------------------------------------------------

// Live packet, little-endian: timestamp u32, PM1/2.5/4/10 u16 (x10), humidity u16 (x100),
// temperature i16 (x100), VOC u16, NOx u16, AQI u16, sensor code u8   <- V2 layout, 23 bytes
// then CO2 ppm u16 (0 = none), battery % u8 (255 = unknown)            <- V3 additions, 26 bytes
static const char *WEB_AQI_SERVICE_UUID = "7b46a200-fd8a-4a28-8f4b-4b3e7c4f0001";
static const char *WEB_AQI_LIVE_UUID    = "7b46a201-fd8a-4a28-8f4b-4b3e7c4f0001";
static const char *WEB_AQI_STATUS_UUID  = "7b46a202-fd8a-4a28-8f4b-4b3e7c4f0001";
static NimBLECharacteristic *liveCharacteristic = nullptr;
static NimBLECharacteristic *statusCharacteristic = nullptr;
static bool bleConnected = false;

static void writeU16(uint8_t *packet, size_t &offset, uint16_t value) {
  packet[offset++] = value & 0xff;
  packet[offset++] = (value >> 8) & 0xff;
}

static void writeU32(uint8_t *packet, size_t &offset, uint32_t value) {
  for (int i = 0; i < 4; i++) packet[offset++] = (value >> (8 * i)) & 0xff;
}

class WebBleServerCallbacks : public NimBLEServerCallbacks {
  void onConnect(NimBLEServer *) override {
    bleConnected = true;
    Serial.println("[BLE] Connected.");
  }
  void onDisconnect(NimBLEServer *) override {
    bleConnected = false;
    Serial.println("[BLE] Disconnected; advertising restarted.");
    NimBLEDevice::startAdvertising();
  }
};

static void updateWebBleStatus() {
  if (!statusCharacteristic) return;
  char status[192];
  snprintf(status, sizeof(status),
           "{\"name\":\"Portable AQI Recorder\",\"board\":\"V3\",\"sensor\":\"%s\",\"co2\":\"%s\","
           "\"battery\":%d,\"recording\":%s,\"samples\":%u,\"capacity\":%u}",
           sensors_pm_name(),
           sensors_has_scd4x() ? sensors_scd_name() : (sensors_has_co2() ? sensors_pm_name() : "none"),
           batteryPercent,
           dataBuffer.isRecording() ? "true" : "false", (unsigned)dataBuffer.getCount(),
           (unsigned)dataBuffer.getCapacity());
  statusCharacteristic->setValue((const uint8_t *)status, strlen(status));
}

static void setupWebBleService() {
  NimBLEDevice::init("AQI Recorder");
  NimBLEDevice::setPower(ESP_PWR_LVL_P9);
  NimBLEServer *server = NimBLEDevice::createServer();
  server->setCallbacks(new WebBleServerCallbacks());
  server->advertiseOnDisconnect(true);

  NimBLEService *service = server->createService(WEB_AQI_SERVICE_UUID);
  liveCharacteristic = service->createCharacteristic(
      WEB_AQI_LIVE_UUID, NIMBLE_PROPERTY::READ | NIMBLE_PROPERTY::NOTIFY);
  statusCharacteristic = service->createCharacteristic(WEB_AQI_STATUS_UUID, NIMBLE_PROPERTY::READ);
  updateWebBleStatus();
  service->start();

  NimBLEAdvertising *advertising = NimBLEDevice::getAdvertising();
  advertising->addServiceUUID(WEB_AQI_SERVICE_UUID);
  advertising->setName("AQI Recorder");
  advertising->setScanResponse(true);
  advertising->start();
  Serial.println("[BLE] Advertising as AQI Recorder.");
}

static void notifyWebBleSample(const SensorSample &s) {
  if (!liveCharacteristic) return;
  uint8_t packet[26];
  size_t offset = 0;
  writeU32(packet, offset, s.timestamp);
  writeU16(packet, offset, s.pm1p0);
  writeU16(packet, offset, s.pm2p5);
  writeU16(packet, offset, s.pm4p0);
  writeU16(packet, offset, s.pm10p0);
  writeU16(packet, offset, s.humidity);
  writeU16(packet, offset, (uint16_t)s.temperature);
  writeU16(packet, offset, s.vocIndex);
  writeU16(packet, offset, s.noxIndex);
  writeU16(packet, offset, s.aqi);
  packet[offset++] = sensors_pm_code();
  writeU16(packet, offset, s.co2);
  packet[offset++] = batteryPercent < 0 ? 255 : (uint8_t)batteryPercent;
  liveCharacteristic->setValue(packet, offset);
  if (bleConnected) liveCharacteristic->notify();
  updateWebBleStatus();
}

// ---------------------------------------------------------------------------
//  Measurement
// ---------------------------------------------------------------------------

static uint16_t scaledU16(float v, float scale) {
  if (!isfinite(v) || v < 0.0f) return 0;
  float x = v * scale;
  return x >= 65535.0f ? 65535 : (uint16_t)x;
}

static void measureAndReport() {
  Reading r;
  bool fresh = sensors_read(r);
  latestSample.co2 = r.co2Ppm;          // CO2 may update even when the PM read didn't
  if (!fresh) return;

  int aqi = max(aqiFromPM25(r.pm2p5), aqiFromPM10(r.pm10p0));
  latestSample.pm1p0       = scaledU16(r.pm1p0, 10.0f);
  latestSample.pm2p5       = scaledU16(r.pm2p5, 10.0f);
  latestSample.pm4p0       = scaledU16(r.pm4p0, 10.0f);
  latestSample.pm10p0      = scaledU16(r.pm10p0, 10.0f);
  latestSample.humidity    = scaledU16(r.humidity, 100.0f);
  latestSample.temperature = isfinite(r.temperature) ? (int16_t)(r.temperature * 100.0f) : 0;
  latestSample.vocIndex    = scaledU16(r.vocIndex, 1.0f);
  latestSample.noxIndex    = scaledU16(r.noxIndex, 1.0f);
  latestSample.aqi         = (uint16_t)max(aqi, 0);
  latestSample.timestamp   = millis() - recordingStartMs;

  if (dataBuffer.isRecording()) dataBuffer.addSample(latestSample);
  notifyWebBleSample(latestSample);

  Serial.printf("PM1 %.1f  PM2.5 %.1f  PM4 %.1f  PM10 %.1f", r.pm1p0, r.pm2p5, r.pm4p0, r.pm10p0);
  if (sensors_has_environment())
    Serial.printf("  RH %.1f%%  T %.1fC  VOC %.0f", r.humidity, r.temperature, r.vocIndex);
  if (sensors_has_nox()) Serial.printf("  NOx %.0f", r.noxIndex);
  if (sensors_has_co2()) Serial.printf("  CO2 %u ppm", r.co2Ppm);
  if (batteryPercent >= 0) Serial.printf("  BAT %d%%", batteryPercent);
  Serial.printf("  | AQI %d [%s]\n", aqi, aqiCategory(aqi));
}

static void updateBattery() {
  unsigned percent;
  batteryPercent = BatteryPwmReader::read(percent) ? (int)percent : -1;
}

// ---------------------------------------------------------------------------
//  Buttons
// ---------------------------------------------------------------------------

static bool fieldAvailable(DataField f) {
  switch (f) {
    case DataField::CO2:         return sensors_has_co2();
    case DataField::NOX_INDEX:   return sensors_has_nox();
    case DataField::VOC_INDEX:
    case DataField::TEMPERATURE:
    case DataField::HUMIDITY:    return sensors_has_environment();
    case DataField::SETTINGS:    return false;   // not a chart
    default:                     return sensors_pm_type() != PmSensor::NONE;
  }
}

static void setBrightnessIndex(uint8_t index) {
  brightnessIndex = index % sizeof(BRIGHTNESS_LEVELS);
  display_set_brightness(BRIGHTNESS_LEVELS[brightnessIndex]);
  prefs.putUChar("bright", brightnessIndex);
}

static void toggleRecording() {
  if (dataBuffer.isRecording()) {
    dataBuffer.setRecording(false);
    Serial.println("[REC] Recording stopped.");
  } else {
    dataBuffer.clear();
    recordingStartMs = millis();
    dataBuffer.setRecording(true);
    Serial.printf("[REC] Recording started (%u samples max).\n", (unsigned)dataBuffer.getCapacity());
  }
  updateWebBleStatus();
}

// In a chart, LEFT/RIGHT step to the previous/next field that can be charted.
static void stepChart(int dir) {
  for (int i = 0; i < NAV_COUNT; i++) {
    navIndex = (navIndex + dir + NAV_COUNT) % NAV_COUNT;
    if (fieldAvailable(navSequence[navIndex])) break;
  }
  cursorField = navSequence[navIndex];
}

static void handleButtons() {
  Button btn = buttons_poll();
  if (btn == Button::NONE) return;
  lastDisplayUpdateMs = 0;   // redraw now

  switch (btn) {
    case Button::LEFT:
    case Button::RIGHT: {
      int dir = (btn == Button::LEFT) ? -1 : 1;
      if (screenMode == ScreenMode::HOME) {
        navIndex = (navIndex + dir + NAV_COUNT) % NAV_COUNT;
        cursorField = navSequence[navIndex];
      } else {
        stepChart(dir);
      }
      break;
    }
    case Button::OK:
      if (screenMode == ScreenMode::CHART) {
        screenMode = ScreenMode::HOME;
      } else if (cursorField == DataField::SETTINGS) {
        setBrightnessIndex(brightnessIndex + 1);
      } else if (fieldAvailable(cursorField)) {
        screenMode = ScreenMode::CHART;
      }
      break;
    case Button::OK_LONG:
      toggleRecording();
      break;
    default:
      break;
  }
}

// ---------------------------------------------------------------------------
//  Display
// ---------------------------------------------------------------------------

static void updateDisplay() {
  unsigned long now = millis();
  if (now - lastDisplayUpdateMs < DISPLAY_UPDATE_INTERVAL_MS) return;
  lastDisplayUpdateMs = now;
  if (screenMode == ScreenMode::HOME) {
    display_home(latestSample, cursorField, dataBuffer.isRecording(), bleConnected,
                 sensors_has_co2(), sensors_has_nox(), sensors_has_environment(), batteryPercent);
  } else {
    display_chart(dataBuffer, cursorField, latestSample);
  }
}

// ---------------------------------------------------------------------------
//  Arduino setup / loop
// ---------------------------------------------------------------------------

void setup() {
  Serial.begin(115200);   // native USB CDC on J1
  unsigned long waitStart = millis();
  while (!Serial && millis() - waitStart < 1500) delay(10);   // don't block without a host

  Serial.println("========================================");
  Serial.println("  Portable AQI Recorder V3 (main Rev B) ");
  Serial.println("========================================");

  buttons_begin();
  display_begin();
  prefs.begin("aqi", false);
  setBrightnessIndex(prefs.getUChar("bright", 0));

  BatteryPwmReader::begin(PIN_BAT_PWM);

  // ~64 KB of history: 2700 samples x 24 bytes = 45 min at 1 Hz.
  if (!dataBuffer.begin(2700)) Serial.println("ERROR: data buffer allocation failed.");

  Wire.begin(PIN_I2C_SDA, PIN_I2C_SCL, 100000);
  sensors_begin(Wire);
  setupWebBleService();

  Serial.printf("Free heap: %u bytes\n", (unsigned)ESP.getFreeHeap());
  recordingStartMs = millis();
}

void loop() {
  if (millis() - lastMeasurementMs >= MEASUREMENT_INTERVAL_MS) {
    lastMeasurementMs = millis();
    updateBattery();
    measureAndReport();
  }
  handleButtons();
  updateDisplay();
  delay(5);
}

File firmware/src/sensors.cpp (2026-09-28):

#include "sensors.h"

#include <SensirionI2CSen5x.h>
#include <SensirionI2cScd4x.h>
#include <SensirionI2cSen63c.h>
#include <SensirionI2cSen65.h>
#include <SensirionI2cSen66.h>
#include <SensirionI2cSen68.h>

// I2C addresses (Sensirion datasheets / drivers).
static constexpr uint8_t ADDR_SEN5X = 0x69;
static constexpr uint8_t ADDR_SEN6X = 0x6B;
static constexpr uint8_t ADDR_SCD4X = 0x62;

static SensirionI2CSen5x sen5x;
static SensirionI2cSen63c sen63c;
static SensirionI2cSen65 sen65;
static SensirionI2cSen66 sen66;
static SensirionI2cSen68 sen68;
static SensirionI2cScd4x scd4x;

static TwoWire *bus = nullptr;
static PmSensor pmType = PmSensor::NONE;
static bool scdFitted = false;
static const char *scdName = "none";
static uint16_t scdCo2 = 0;   // last SCD4x reading; it updates every 5 s

static bool present(uint8_t addr) {
  bus->beginTransmission(addr);
  return bus->endTransmission() == 0;
}

// ---- SEN5x (J3) ----

static PmSensor startSen5x() {
  sen5x.begin(*bus);
  if (sen5x.deviceReset()) return PmSensor::NONE;
  delay(100);
  unsigned char name[32] = {0};
  PmSensor type = PmSensor::SEN50;   // SEN50 has no product-name variant suffix to rely on
  if (!sen5x.getProductName(name, sizeof(name))) {
    String s = String((char *)name);
    s.trim();
    if (s == "SEN55") type = PmSensor::SEN55;
    else if (s == "SEN54") type = PmSensor::SEN54;
  }
  if (sen5x.startMeasurement()) return PmSensor::NONE;
  return type;
}

// ---- SEN6x (J4) ----
// Every SEN6x answers the same product-name command, so any driver can identify it.

static PmSensor startSen6x() {
  sen66.begin(*bus, ADDR_SEN6X);
  if (sen66.deviceReset()) return PmSensor::NONE;
  delay(1200);                       // SEN6x device-reset time
  int8_t name[32] = {0};
  if (sen66.getProductName(name, sizeof(name))) return PmSensor::NONE;
  String s = String((const char *)name);
  s.trim();
  int16_t err;
  PmSensor type;
  if (s == "SEN66") {
    type = PmSensor::SEN66; err = sen66.startContinuousMeasurement();
  } else if (s == "SEN63C") {
    sen63c.begin(*bus, ADDR_SEN6X); type = PmSensor::SEN63C; err = sen63c.startContinuousMeasurement();
  } else if (s == "SEN65") {
    sen65.begin(*bus, ADDR_SEN6X); type = PmSensor::SEN65; err = sen65.startContinuousMeasurement();
  } else if (s == "SEN68") {
    sen68.begin(*bus, ADDR_SEN6X); type = PmSensor::SEN68; err = sen68.startContinuousMeasurement();
  } else {
    Serial.printf("[SENS] Unknown SEN6x product name '%s'\n", s.c_str());
    return PmSensor::NONE;
  }
  return err ? PmSensor::NONE : type;
}

// SEN6x reports "not available yet" as all-ones raw values; the drivers only scale them.
static float pmOrNan(float v)  { return v >= 6553.4f ? NAN : v; }   // 0xFFFF / 10
static float rhOrNan(float v)  { return v >= 327.66f ? NAN : v; }   // 0x7FFF / 100
static float tOrNan(float v)   { return v >= 163.83f ? NAN : v; }   // 0x7FFF / 200
static float idxOrNan(float v) { return v >= 3276.6f ? NAN : v; }   // 0x7FFF / 10

static bool readSen6x(Reading &r) {
  float pm1, pm25, pm4, pm10, rh, t, voc = NAN, nox = NAN;
  uint16_t co2 = 0xFFFF;
  int16_t err;
  switch (pmType) {
    case PmSensor::SEN66:
      err = sen66.readMeasuredValues(pm1, pm25, pm4, pm10, rh, t, voc, nox, co2);
      break;
    case PmSensor::SEN63C: {
      int16_t c = 0x7FFF;
      err = sen63c.readMeasuredValues(pm1, pm25, pm4, pm10, rh, t, c);
      co2 = (c == 0x7FFF || c < 0) ? 0xFFFF : (uint16_t)c;
      break;
    }
    case PmSensor::SEN65:
      err = sen65.readMeasuredValues(pm1, pm25, pm4, pm10, rh, t, voc, nox);
      break;
    case PmSensor::SEN68: {
      float hcho;
      err = sen68.readMeasuredValues(pm1, pm25, pm4, pm10, rh, t, voc, nox, hcho);
      break;
    }
    default:
      return false;
  }
  if (err) return false;
  r.pm1p0 = pmOrNan(pm1); r.pm2p5 = pmOrNan(pm25); r.pm4p0 = pmOrNan(pm4); r.pm10p0 = pmOrNan(pm10);
  r.humidity = rhOrNan(rh); r.temperature = tOrNan(t);
  r.vocIndex = idxOrNan(voc); r.noxIndex = idxOrNan(nox);
  r.co2Ppm = (co2 == 0xFFFF) ? 0 : co2;
  return true;
}

static bool readSen5x(Reading &r) {
  float pm1, pm25, pm4, pm10, rh, t, voc, nox;
  if (sen5x.readMeasuredValues(pm1, pm25, pm4, pm10, rh, t, voc, nox)) return false;
  r.pm1p0 = pm1; r.pm2p5 = pm25; r.pm4p0 = pm4; r.pm10p0 = pm10;
  r.humidity = rh; r.temperature = t; r.vocIndex = voc; r.noxIndex = nox;   // NAN where absent
  return true;
}

// ---- SCD4x (CO2 island, fitted by hand): SCD40, SCD41 or SCD43 ----
// All three share the package, I2C address and periodic-measurement commands used here.

static bool startScd4x() {
  scd4x.begin(*bus, ADDR_SCD4X);
  scd4x.wakeUp();                    // SCD41/43 only; ignored (not even acknowledged) otherwise
  scd4x.stopPeriodicMeasurement();   // in case it kept running across an MCU reset
  delay(500);
  if (scd4x.reinit()) return false;
  delay(30);
  SCD4xSensorVariant variant;        // only readable in idle mode, i.e. before starting
  if (!scd4x.getSensorVariant(variant)) {
    switch (variant & SCD4X_SENSOR_VARIANT_MASK) {
      case SCD4X_SENSOR_VARIANT_SCD40: scdName = "SCD40"; break;
      case SCD4X_SENSOR_VARIANT_SCD41: scdName = "SCD41"; break;
      case SCD4X_SENSOR_VARIANT_SCD42: scdName = "SCD42"; break;
      case SCD4X_SENSOR_VARIANT_SCD43: scdName = "SCD43"; break;
      default: scdName = "SCD4x"; break;
    }
  } else {
    scdName = "SCD4x";
  }
  return scd4x.startPeriodicMeasurement() == 0;
}

static void pollScd4x() {
  bool ready = false;
  if (scd4x.getDataReadyStatus(ready) || !ready) return;
  uint16_t co2;
  float t, rh;
  if (!scd4x.readMeasurement(co2, t, rh) && co2 > 0) scdCo2 = co2;
}

// ---- Public API ----

void sensors_begin(TwoWire &wire) {
  bus = &wire;
  delay(50);   // sensor power-up after the board switch turns on
  if (present(ADDR_SEN5X)) pmType = startSen5x();
  if (pmType == PmSensor::NONE && present(ADDR_SEN6X)) pmType = startSen6x();
  scdFitted = present(ADDR_SCD4X) && startScd4x();
  if (!scdFitted) scdName = "none";
  Serial.printf("[SENS] PM sensor: %s, CO2 sensor: %s\n", sensors_pm_name(), scdName);
}

bool sensors_read(Reading &out) {
  if (scdFitted) pollScd4x();
  Reading r;
  bool ok = false;
  if (pmType == PmSensor::SEN50 || pmType == PmSensor::SEN54 || pmType == PmSensor::SEN55) ok = readSen5x(r);
  else if (pmType != PmSensor::NONE) ok = readSen6x(r);
  if (ok) out = r;
  // The SCD4x on its isolated island is preferred over a SEN6x's built-in CO2.
  if (scdFitted && scdCo2) out.co2Ppm = scdCo2;
  return ok;
}

PmSensor sensors_pm_type() { return pmType; }
bool sensors_has_scd4x() { return scdFitted; }
const char *sensors_scd_name() { return scdName; }

bool sensors_has_environment() {
  return pmType == PmSensor::SEN54 || pmType == PmSensor::SEN55 || pmType == PmSensor::SEN65 ||
         pmType == PmSensor::SEN66 || pmType == PmSensor::SEN68;
}
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

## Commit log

2026-03-04 Working code; Fixed libraries
    [main.cpp]
2026-04-24 Added display and buttons
2026-05-03 Gemini fixed UI spillage
    [display.cpp]
2026-09-28 Display and AQI updates; correct SEN5x pinout
    - ST7789 240x320 display rendering reworked; values above 999 shown as 1.0K etc.
    - AQI above 500 continues the 301-500 slope (EPA guidance) instead of clamping at 999
    - Host regression checks (scripts/test_aqi.py) and a host display test harness
    - README: SEN5x connector pins 3/4 are SDA/SCL per Sensirion's drawing
    [display.cpp, main.cpp]
2026-09-28 V3: custom PCB (main board rev B, 2-layer 47 x 76 mm)
    - hardware/rev-b/main: ESP32-C3-MINI-1 main board, fully routed (ERC 0,
    DRC 0 errors / 0 unconnected / 0 parity), JLC BOM/CPL, cost, renders
    - E-paper through an external adapter (J6, DESPI-C02 order), TFT default
    - CO2 island on top, fed through its bottom-right tab; CO2 supply fitted,
    SCD41, J6 and J8 unfitted
    - hardware/rev-a and older rev-b battery/main designs kept as history
    - The IP5310 battery board moved to devalopr/18650-USB-C-UPS
    [AQI_Battery.dsn, AQI_Battery.kicad_pcb, AQI_Battery.kicad_sch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]
2026-09-28 V3: main PCB only
    - Remove the Super Mini firmware, web app and tools (they live on V2)
    - Remove Rev A and the superseded main-pwm schematic (in git history)
    - Older battery designs moved to devalopr/18650-USB-C-UPS (history/)
    - Keep the Rev A baseline design.json the design script starts from,
    the design brief, and datasheets for parts on this board
    - Telemetry keeps only the ESP32 receiver; the CH32 transmitter is in
    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
    [AQI_Battery.dsn, AQI_Battery.kicad_pcb, AQI_Battery.kicad_sch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]
2026-09-28 Firmware for the V3 main board
    PlatformIO/Arduino firmware in firmware/, ported from the V2 Super Mini
    firmware to the Rev B main board:
    - Rev B pin map: TFT on DC 10 / CS 4 / SCK 5 / MOSI 6 / RST 7, backlight
    PWM on GPIO3, I2C on GPIO0/1, buttons on GPIO8/9/2, battery PWM on GPIO21
    - Auto-detects SEN50/54/55 (0x69) or SEN63C/65/66/68 (0x6B), and any
    SCD4x (SCD40/41/43) on the CO2 island; real CO2 on the home screen
    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
